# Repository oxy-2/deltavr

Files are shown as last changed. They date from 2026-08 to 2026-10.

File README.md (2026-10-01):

hi im oxy and im working with 2 of my friends (John/monizjoao and grand/merekelene) now to bring everyone a opensource, pcvr, light weight slam tracked headset with constellation tracked controllers and if you are able to source the parts right it could be possible to build your own under 700 euros.

# deltavr

## summary
so to sum up everything in this project, the pcbs are custom for the headset and for the controllers, we are using high performance imus those being the lsm6dsvs, the pcbs are majority smd, the controllers and headset use the widely available and powerfull NRF52840 "pro micro" boards of which are similar to the nice!nano v2, from communication between the headset and controllers gt-24 nrf24l01 boards are used which allows for antennas externally but work great with the MIFA they have, our optics are a big point of this headset too, being that they are pseudo pancakes, basically two fresnels stacked in a way that we can get close to pancake performance but instead of spending hundreds its about 20 euros in total, the entire headset apart from the linear rods is 3d printable and we are doing ours in asa which we will smooth later to get a very nice smooth finish, the headset uses 5 OV9281 120fps global shutter usb cameras which go to a usb 3.2 gen 2 hub which then goes to a pc, speaking of obviously this headset is pcvr, maybe some day it will be mobile but we dont have anything yet in plans for such a thing for the first versions atleast, the last couple points woud be that the controllers are actually nice, sporting a tmr joystick to ensure they do not drift ever while using a low ammount of battery and also 2 hall effect triggers allowing for not just on of off triggers but a range of values.

## reasoning on protocols used:
firstly the usb cameras, they are expensive, alot more so that mipi when they are the usb version, but we do not have any real way of actually converting camera mipi to one central usb as that would alone be an engineering project, secondly the protocol for the mcus to communicate is Nordic Semi's ESB (Enhanced ShockBurst) protocol which we are using for better battery life with great connectivity.

## what we have done right now
as of writing this (october 1st 2026) we have the PCBs fully completed which i did over the previous summer, we have the full bill of materials and general plan too done and a general idea of the 3d design for the controllers while we are actively modeling the headset rn and have it about 30% done id say, the PCBs do need one made for the left version of the controllers but that is a very simple thing to do and i will be doing it soon, along with a full bom we have all the parts fully sourced and ready for purcahse through aliexpress and alibaba for their competetive pricing of electronic components and availability of them, we are sourcing really just the cameras from alibaba and also the imus we are purchasing in bulk from a seller directly who was found on alibaba at first.

## where can you see our work?
well theres my personal site at oxygenated.uk but i still need to update its information and then theres this github repository and the weekly reports for thirdspace my team and i write which include lapse links of which can be used to view all the work we have done in a time lapse format.

thank you for your time.

\-oxy <3

JohnTarkov: Hi im JohnTarkov Im working on the project too and i updated this so i can get my hacktime functioning for the project to use Lookout to record my project.

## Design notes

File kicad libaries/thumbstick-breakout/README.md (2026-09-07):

# "PS5 Hall Effect" Compatible Thumbstick Breakout Board
This breakout board is designed to be a drop-in replacement for the Sparkfun BOB-09110 but using hall effect thumbsticks instead of low quality "PS2 style" sticks.

These thumbstick components are widely available on Ali Express as replacement thumbsticks for game controllers. Unlike a traditional potentiometer based joystick, these sticks only operate with a specific polarity, so ensure you select one meant specifically for the PS5 to match the design of this board.

PCBWay order link:<br/>
https://www.pcbway.com/project/shareproject/_PS5_Hall_Effect_Thumbstick_Breakout_Board_abc13f47.html<br/>
(10 for $5 at time of writing. I get a small commission.)




## Datasheet
I couldn't find a datasheet for these stick components, but the datasheet for [this alternative](https://mm.digikey.com/Volume0/opasdata/d220001/medias/docus/2608/THB001P%20drawing.pdf) stick seemed to have measurement information the exact same footprint, so it was used in the creation of this board.

## License
Copyright (c) Daniel Benoy

Distributed under the terms of the [Creative Commons ShareAlike 4.0 International](https://creativecommons.org/licenses/by-sa/4.0/) license.

THESE FILES ARE PROVIDED BY THE COPYRIGHT HOLDERS AND CONTRIBUTORS “AS IS” AND ANY EXPRESS OR IMPLIED WARRANTIES, INCLUDING, BUT NOT LIMITED TO, THE IMPLIED WARRANTIES OF MERCHANTABILITY AND FITNESS FOR A PARTICULAR PURPOSE ARE DISCLAIMED. IN NO EVENT SHALL THE COPYRIGHT OWNER OR CONTRIBUTORS BE LIABLE FOR ANY DIRECT, INDIRECT, INCIDENTAL, SPECIAL, EXEMPLARY, OR CONSEQUENTIAL DAMAGES (INCLUDING, BUT NOT LIMITED TO, PROCUREMENT OF SUBSTITUTE GOODS OR SERVICES; LOSS OF USE, DATA, OR PROFITS; OR BUSINESS INTERRUPTION) HOWEVER CAUSED AND ON ANY THEORY OF LIABILITY, WHETHER IN CONTRACT, STRICT LIABILITY, OR TORT (INCLUDING NEGLIGENCE OR OTHERWISE) ARISING IN ANY WAY OUT OF THE USE OF THIS SOFTWARE, EVEN IF ADVISED OF THE POSSIBILITY OF SUCH DAMAGE.

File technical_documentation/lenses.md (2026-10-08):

# DeltaVR - dual fresnel optics

> [!summary] summary
> d.70 pmma fresnels, **2 mm** thick each. stack is **f40 (display) + f30 (eye)**, grooves side meeting at the middle seperated by the gasket (*0.2mm*)
> combined efl **≈ 17.2 mm**. display gap is **15.0 mm**. eye relief is **20 mm** design (15–22 band). 10 mm is lashes-on-glass and the nose will not fit.

**parts:** d70 fl30 (top) + d70 fl40(bottom), 5 € ish each also buy spares. 

**cut outline:** see `deltavr-lens-cut.png` (optical center on pupil, nose bite, mirror L/R). trim does **not** change focal length (fl).

---

## 1. layout

```
display active surface
   │
   |  15.0 mm air          <-- dist. to disp. from len not holder, thats 14mm
   ▼
   f40 fresnel  2 mm       flat side toward display, grooves inward
   │
   │  0.2 mm spacer        printed as first layer (ring, not take up fov too much)
   ▼
   f30 fresnel  2 mm       grooves inward, flat toward eye <- top is more focused
   │
   │  20 mm air            eye relief (15–22 band, 25 if glasses)
   ▼
cornea of eye
```

| gap | value | notes |
| --- | --- | --- |
| display -> f40 flat | **15.0 mm**  | caliper this. 14 = near focus, 15 = infinity-ish, 16 = far bias |
| f40 thickness | **2.0 mm** | catalog, cat. shouldnt change |
| between lenses | **0.2 mm** | grooves face each other. ring spacer, not a disc |
| f30 thickness | **2.0 mm** | catalog |
| f30 flat -> eye | **20 mm** | design. 15–22 band. 25 if glasses. 10 = lashes + nose smash |
| **optical module** | **19.2 mm**  | display face → outer face of eye lens. cylinder depth |
| **display -> cornea** | **~39.2 mm** | includes eye-relief air. do **not** put this in the barrel |

---

## 2. sign convention

real-is-positive, thin-lens form:

$$\frac{1}{f} = \frac{1}{d_o} + \frac{1}{d_i}$$

virtual image (eyepiece case) → $d_i < 0$.

---

## 3. single lens

| symbol | meaning | value |
|---|---|---|
| $f$ | focal length (efl) | 30 mm or 40 mm |
| $d_o$ | object distance (display → lens) | solve |
| $d_i$ | image distance (lens → image) | $-\infty$ or $-250\ \mathrm{mm}$ |
| $t$ | substrate thickness | **2.0 mm** |
| $n$ | pmma index | 1.49 (catalog fl already includes this) |

> [!note] fresnel fl reference
> catalog fl is measured from the **grooved surface**. the 2 mm blank is mechanical dead plastic; power lives on the grooves. that is why $g_{\mathrm{disp}} = \mathrm{FFL} - t$.

---

## 4. two thin lenses, separation $d$

groove-to-groove: $d = 0.2\ \mathrm{mm}$.

$f_1 = 40$ (display side), $f_2 = 30$ (eye side).

### equivalent focal length

$$\frac{1}{f_{\mathrm{eq}}} = \frac{1}{f_1} + \frac{1}{f_2} - \frac{d}{f_1 f_2}$$

$$\frac{1}{f_{\mathrm{eq}}} = \frac{1}{40} + \frac{1}{30} - \frac{0.2}{40 \cdot 30} = 0.025 + 0.033333 - 0.000167 = 0.058167$$

$$\boxed{f_{\mathrm{eq}} = 17.19\ \mathrm{mm}}$$

contact limit ($d \approx 0$):

$$f = \frac{f_1 f_2}{f_1 + f_2} = \frac{1200}{70} = 17.14\ \mathrm{mm}$$

---

## 5. front focal length (display placement)

object at front focal point → image at infinity (relaxed eye). ffl is measured from the **first lens groove plane** ($L_1$ = f40).

$$\mathrm{FFL} = f_{\mathrm{eq}}\left(1 - \frac{d}{f_2}\right) = 17.19 \times 0.99333 = 17.08\ \mathrm{mm}$$

principal-plane offset from $L_1$ is $\bar{H_1} = -f_{\mathrm{eq}}\, d / f_2 \approx -0.12\ \mathrm{mm}$. negligible. treat the f40 groove plane as the front reference.

**mechanical gap (flat → display):**

$$\boxed{g_{\mathrm{disp}} = \mathrm{FFL} - t_1 = 17.08 - 2.0 = 15.1\ \mathrm{mm} \approx 15.0\ \mathrm{mm}}$$

---

## 6. focus target (not just infinity)

$$\frac{1}{d_o} = \frac{1}{f_{\mathrm{eq}}} - \frac{1}{d_i}, \qquad d_i = -|d_i|\ \text{(virtual)}$$

$$d_o = \left(\frac{1}{f_{\mathrm{eq}}} + \frac{1}{|d_i|}\right)^{-1}$$

$$\boxed{g_{\mathrm{disp}}(d_i) = \left(\frac{1}{f_{\mathrm{eq}}} + \frac{1}{|d_i|}\right)^{-1} - t_1}$$

| target image | $\|d_i\|$ | $d_o$ (to groove) | $g_{\mathrm{disp}} = d_o - t_1$ |
|---|---|---|---|
| infinity (relaxed) | $\infty$ | 17.1 mm | **15.1 mm** |
| 2 m (far) | 2000 | 16.4 mm | 14.4 mm |
| 25 cm (reading) | 250 | 16.1 mm | **14.1 mm** |
| 10 cm (too close) | 100 | 14.4 mm | 12.4 mm |
| 6 cm (why 13.2 hurts) | 58 | 13.2 mm | 11.2 mm |

> [!warning] old 13.2 mm gap
> manolo's measured 13.2 mm doesnt match 30+40 thin lens math. it puts the virtual image at ~6 cm and eyes will hate it. if a housing is already cut at 13.2, print a ~2 mm shim. design point is **15.0 mm**, shim range **14–16 mm**.

---

## 7. eye side

firstly, eye relief is mechanical not optical:

$$g_{\mathrm{eye}} = \mathrm{cornea} - \mathrm{f30\ flat}$$

| use | $g_{\mathrm{eye}}$ |
| --- | --- |
| lashes / fantasy | 8–10 mm |
| aggressive nose trim | 15–18 mm |
| **design (fits a face)** | **20 mm** |
| glasses / easy fit | 22–25 mm |

10 mm is eyelashes on the flat. the nose also will not fit: nose tip sits ~25–45 mm in front of the cornea, so at 10 mm relief the bridge is still deep inside the lens volume. 20–25 mm is the real mechanical floor for a full ø70 stack and a normal nose. closer than that needs a molded face interface almost nobody will print right on try one.

first-order fov does **not** care about relief. relief buys eye box and clearance.

$$r_{\mathrm{clear}} \gtrsim g_{\mathrm{eye}} \cdot \tan(\mathrm{FOV}/2) + \mathrm{eye\ box}/2 + r_{\mathrm{pupil}}$$

at fov 75°/axis (tan 38° ≈ 0.78) and a 5 mm eye box:

| $g_{\mathrm{eye}}$ | $r_{\mathrm{clear}}$ needed | note |
|---|---|---|
| 10 mm | ~16 mm | easy, but lashes |
| 20 mm | ~23 mm | keep this radius on the **temple + top** |
| 25 mm | ~27 mm | almost untrimmed ø70, nose dies |

so: do **not** shrink the whole lens. cut a **nose bite only** (manolo kidney / d-shape). keep r = 35 mm on the outer, top, and bottom-temporal edges. inboard at pupil height, clear down to ~18 mm from the optical center (≈13 mm from midline at 63 ipd). below pupil height the bite opens more for the nose body.

inboard eye box will be tighter than outboard. that is normal. lose a little binocular overlap before you lose temple fov.

---

## 8. full stack length

### optical module

ends at the outer face of the eye lens, **not** at the cornea.

$$L_{\mathrm{mod}} = g_{\mathrm{disp}} + t_1 + d + t_2$$

$$L_{\mathrm{mod}} = 15.0 + 2.0 + 0.2 + 2.0 = \mathbf{19.2\ \mathrm{mm}}$$

### display → cornea

$$\boxed{L_{\mathrm{total}} = g_{\mathrm{disp}} + t_1 + d + t_2 + g_{\mathrm{eye}} = 15.0 + 2.0 + 0.2 + 2.0 + 20.0 = 39.2\ \mathrm{mm}}$$

| $g_{\mathrm{eye}}$ | $L_{\mathrm{total}}$ display→cornea | housing $W_{\mathrm{FB}}$ (approx) |
|---|---|---|
| 15 mm | 34.2 mm | ~44 mm |
| **20 mm (design)** | **39.2 mm** | **~49 mm** |
| 25 mm | 44.2 mm | ~54 mm |

quest 2 body is ~48 mm. 20 mm relief puts us at quest-class thickness, not "thin". the thin goal dies here unless relief or the optical module shrinks. do not fake it with 10 mm.

### housing front-back (mechanical)

$$W_{\mathrm{FB}} = t_{\mathrm{display\ PCB}} + t_{\mathrm{cover}} + L_{\mathrm{mod}} + g_{\mathrm{eye}} + t_{\mathrm{face\ gasket}}$$

$$\approx 5 + 1 + 19.2 + 20 + 4 \approx \mathbf{49\ \mathrm{mm}} \quad (\sim 45\ \mathrm{mm}\ \text{if pcb+gasket squeezed})$$

> [!danger] dont double count
> do not put eye relief inside the optical cylinder. module is 19.2 mm. the 20 mm of air in front of the eye is outside the barrel.

> [!warning] nose bridge
> no solid bar between the lens bottoms. the nose has to climb into the open gap after the nose bite. route structure over the top and along the temples. face gasket gets a deep nose cutout that matches the lens bite.

---

## 9. fov

panel is the LS029B3SX02, active $w = 26.6\ \mathrm{mm}$, half-width $h = 13.3\ \mathrm{mm}$.

### ideal

$$\mathrm{FOV}_{1\mathrm{D}} = 2 \arctan\left(\frac{h}{f_{\mathrm{eq}}}\right) = 2 \arctan\left(\frac{13.3}{17.19}\right) = \mathbf{75.4°}$$

diagonal (square panel, half-diag $= h\sqrt{2}$):

$$\mathrm{FOV}_{\mathrm{diag}} = 2 \arctan\left(\frac{h\sqrt{2}}{f_{\mathrm{eq}}}\right) = 2 \arctan\left(\frac{18.81}{17.19}\right) = \mathbf{95.2°}$$

general:

$$\boxed{\mathrm{FOV} = 2 \arctan\left(\frac{d_{\mathrm{sensor}}}{2\, f_{\mathrm{eq}}}\right)}$$

### real (relief + diameter losses)

relief does not change the 75°/axis first-order number. it changes whether your pupil can sit in the ray bundle (eye box) and how hard the nose bite clips the inboard field.

$$r_{\mathrm{clear}} \gtrsim g_{\mathrm{eye}} \cdot \tan(\mathrm{FOV}/2) + \mathrm{eye\ box}/2 + r_{\mathrm{pupil}}$$

keep r ≥ 23 mm on temple/top at 20 mm relief. nose bite can go down to ~18 mm from the optical center inboard. expect **5–10° less** on the diagonal after nose bite + a little eye-box loss. still quest 2-class (~75° / ~95° ideal).

---

## 10. alternate stack (two f30s)

only real shrink lever. same blank, same cutout, one part number.

$$f_{\mathrm{eq}} = \frac{30 \cdot 30}{30 + 30} = 15.0\ \mathrm{mm}$$

$$g_{\mathrm{disp}} = 15.0 - 2.0 = 13.0\ \mathrm{mm}$$

$$L_{\mathrm{total}} = 13 + 2 + 0.2 + 2 + 20 = 37.2\ \mathrm{mm}$$

$$\mathrm{FOV}_{1\mathrm{D}} = 2\arctan(13.3/15) = 82.0°$$

| stack | efl | display gap | display→cornea ($g_{\mathrm{eye}}=20$) | fov / axis |
|---|---|---|---|---|
| **f40 + f30** (current) | 17.2 mm | 15.0 mm | 39.2 mm | 75° |
| f30 + f30 | 15.0 mm | 13.0 mm | 37.2 mm | 82° |

f30+f30 buys +7°/axis and 2 mm less path. it does not fix the nose. nose is trim + gasket + open nose bridge.

---

## 11. diameter (keep ø70)

matching diameters with **both** fl30 and fl40 in the listing:

| diameter | fl30 | fl40 | both? |
|---|---|---|---|
| **d70** | yes | **yes** | **only option** |
| d90 | yes | (fl50) | no |
| d100 | | yes | no |
| d60 | yes | (fl80) | no |
| d50 / d40 | no | no | no |

d100 fl120 at 10 € is a trap. cutout work stays valid on ø70.

---

## 12. variable sheet

| variable | symbol | formula | value |
|---|---|---|---|
| display-side fl | $f_1$ | catalog | 40 mm |
| eye-side fl | $f_2$ | catalog | 30 mm |
| lens thickness | $t_1, t_2$ | catalog | 2.0 mm each |
| spacer | $d$ | first layer | 0.2 mm |
| combined efl | $f_{\mathrm{eq}}$ | $\left(\frac{1}{f_1}+\frac{1}{f_2}-\frac{d}{f_1 f_2}\right)^{-1}$ | **17.19 mm** |
| front focal length | ffl | $f_{\mathrm{eq}}(1 - d/f_2)$ | 17.08 mm |
| display gap (mech) | $g_{\mathrm{disp}}$ | $\mathrm{FFL} - t_1$ | **15.0 mm** |
| focus target | $d_i$ | design choice | $\infty$ or $-250\ \mathrm{mm}$ |
| object distance | $d_o$ | $\left(\frac{1}{f_{\mathrm{eq}}}+\frac{1}{\|d_i\|}\right)^{-1}$ | 17.1 / 16.1 mm |
| eye relief | $g_{\mathrm{eye}}$ | mechanical | **20 mm** (15–22) |
| optical module | $L_{\mathrm{mod}}$ | $g_{\mathrm{disp}}+t_1+d+t_2$ | **19.2 mm** |
| display→cornea | $L_{\mathrm{total}}$ | $L_{\mathrm{mod}}+g_{\mathrm{eye}}$ | **39.2 mm** |
| half panel | $h$ | $w/2$ | 13.3 mm |
| fov / axis | $\mathrm{FOV}_{1\mathrm{D}}$ | $2\arctan(h/f_{\mathrm{eq}})$ | **75°** |
| fov diagonal | $\mathrm{FOV}_{\mathrm{diag}}$ | $2\arctan(h\sqrt{2}/f_{\mathrm{eq}})$ | **95°** |
| diameter | $D$ | keep cutout | 70 mm |
| ior | $n$ | pmma | 1.49 |

---

## 13. what is *not* in the math

- **$t = 2\ \mathrm{mm}$ does not change $f$.** fresnel power is the groove prism angles. thickness only enters as $g_{\mathrm{disp}} = \mathrm{FFL} - t$ because catalog fl is from the grooves.
- **cutting the outline does not change $f$.** trim is mechanical only.
- **thick-lens principal-plane shift** $\bar{H} \sim t/n \approx 1.3\ \mathrm{mm}$ matters for bulk lenses. for a fresnel with all power at one face, the principal plane sits at the grooves. already handled.
- **seidel aberrations, distortion, astigmatism.** not first-order. the pair (stronger toward the eye) trims some spherical aberration vs a single element; it does not change the first-order numbers above.

---

## 14. build rules

1. optical center (groove center) stays on the pupil.
2. grooves meet in the middle; flats face display and eye.
3. f30 (shorter fl, "more focused") goes toward the **eye**. f40 toward the **display**.
4. spacer is a ø70 **ring** (od 70, id = clear aperture). nothing plastic over the optical zone.
5. no soldering iron on faces. acrylic cement on the outer rim only, or a mechanical ring cassette. heat warps grooves and the lens is dead.
6. mirror the cut outline for left/right. hand-trim is the known-good path.
7. shim the display gap. 15.0 mm nominal, 14–16 mm is the useful window.
8. **nose bite only**, do not shrink the whole blank. keep r = 35 mm outer/top. inboard at pupil height cut to ~18 mm from optical center. below pupil the bite opens for the nose body. see `deltavr-lens-cut.png`.
9. face gasket gets a deep nose cutout matching the bite. no solid nose bridge bar between the lens bottoms.
10. eye relief 20 mm nominal. 15 mm if the trim is aggressive and the face is narrow. 25 mm for glasses. never 10 mm.

---

## 15. summary

$$f_{\mathrm{eq}} = 17.2\ \mathrm{mm} \implies g_{\mathrm{disp}} = f_{\mathrm{eq}} - 2 = 15.0\ \mathrm{mm}$$

$$L_{\mathrm{total}} = 15+2+0.2+2+20 = 39.2\ \mathrm{mm}, \quad \mathrm{FOV} \approx 75°/95°$$

eye relief 20 mm (15–22). 10 mm is lashes and no nose. fov is set by display / efl, not by relief. relief buys nose clearance and eye box. cut a nose bite, keep the rest of the ø70.

---

*deltavr optics · 2 mm pmma · ø70 · f40+f30 · spacer 0.2 mm*

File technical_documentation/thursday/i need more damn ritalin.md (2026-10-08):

okay so to get started we have some objectives, right now we are putting the modelling work on hold until this weekend when we work in unison and show grand and explain how to model in onshape, we have renode to lean too, joao and me we need to get it working on our computers so we can work with grand in unison properly on not just the modelling as the headset is getting more and more polished.

to do list:

- [ ] we need to transfer all products to be purchased over to alibaba and make a propper list of all the tools we will be buying

- [ ] apply for funding with hackclub blueprint and the other hackclub funding thing

- [x] figure out the logistics of hand shipping through europe, mainly latvia to poland

- [ ] build a custom pcb for the smol slimes to be sold to reimburse the price of the headset

- [ ] purchase the screens and lenses

- [ ] fix the 3d printer

- [ ] model the controllers

- [ ] build the first physical prototype of the current hmd model to physically modify it to figure out what to model

- [ ] get and setup the "open" chromebooks that are to be given by Prof. M. 

- [ ] get a good night of sleep

- [ ] read the bible verse that was supposed to be read

- [ ] talk with grand on how shipping and purchasing will be done

- [ ] set a concrete date to buy the imus and also start negotiating the shipping price on other items to be sent to Latvia for lower prices

- [ ] figure out swiss to madeira / slovakia to madeira "buisness trip" if it is selected to be done

- [ ] get confirmation to skip school for days for flight

- [ ] write the portugese translation of your work from pt class

- [ ] test and recalibrate the printer to work with a 0.4 / 0.3 brass nozzle with asa for precision

- [ ] ensure the printer is setup to do overnight prints propperly

- [ ] make sure the enclosure works

- [ ] get money for next week lunches

- [ ] get 11 eur and pay it back over time to get out of debt

- [ ] take a break tmrw and wake up late

- [ ] propperly maintain documentation

- [ ] setup obsidian and git on the school chromebook for writing documentation in free time

- [ ] talk with joao

- [ ] start work on the modeling of the controllers

- [ ] practice soldering and desoldering smd caps and resistors and small qfn parts

- [ ] find out about buying more filament

- [ ] figure out abt getting my ship accepted on stardance

- [ ] buy pcbs with stardance

- [ ] figure out how to get mimo to be accessible thru my phone

i think for now thats about it.

okay so my issue is that i need to propperly organize this all and have everything worked through piece by piece and the rest of my time i spend writing and planning this all out and i need to figure out how to have a connection to my agent at home or my harness and its memory, ill figure it out, yeah lemme add that.

okay i will get started with alibaba transfer of all the items we are gonna buy

and i need to remember every screenshot with my info in it or sum is a screenshot and minute i have to entirely cut from what ive done, use your phone if you need something, never the pc.

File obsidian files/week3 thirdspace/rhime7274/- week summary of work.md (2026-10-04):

so this week was amazing, me and João did a bunch of work together and the model is really getting to its closer to actually being done and its really exciting to see.

so firstly our first design of the lenses was utter dogshit icl heres a peep from the images in the last devlog lol.

![[old lenses.png]]

anyways so you can see first of all the lenses were uncut and well this one actually didnt have lenses lol but yeah so like it had the lenses separated as far as possible vertically where as it turns out you actually dont want that, you can refer to my documentation on how it actually works if you want its well ill just link it buts a obsidian link yk, anyways [here](obsidian://open?vault=GitHub&file=deltavr%2Ftechnical_documentation%2Flenses%20assembly%20and%20lenses%20formulas%2Flenses)

so you can see with the calculations and such to back it up there, but in short you want the lenses as close together as possible and as long as you can get them close which we had to space em but yeah, but yeah if you can get em close you can have em close to the screen, very close and then have your face like only 10mm away for eye relief so like it cuts down the size a lot which is a massive bonus considering how cheap it is of an upgrade only needing one extra lens pair, anyways so we like ended modeling out the like double lens guy heres a photo.

![[new lenses.png]]

so as you can see the two lenses stacked there on the left thats without the like assembly to hold em in place, the gasket between the two lenses to not damage either, and also some holes for mounting and well yeah mounting is a big point of the assembly, i want them to just slot into the like screen area so its like easy to swap em out if you need, tho tbf if you wanna take this thing apart its gonna be like a puzzle lmao anyways you can also see an area in the top dug out, thats for the display connectors which are mirrors of eachother to go to one guy that turns em into just one mipi connection which goes back to our driver board, heres a pick of the small combination board and the bigger driver board.

![[mipi to hdmi board.png]]

straight off aliexpress im sure you can tell, anyways these actually just come right with the screens we are getting which is great and should run at 90hz which will not make the judges hurl which is good but the displays can hit 120hz its a driver limitation but if we spent uhh i say 40 euros more which is a big stretch icl we can use 120hz displays, heres a looksie at the driver board for those.

![[the better mipi to hdmi board.png]]

here you can see it, also i think it offers seperate like mipi ribbons for each rather than one split, which is kinda awesome and i fw the black but its just too expensive to really be viable cuz its a 40 euro bump best case and a 60 or even 80 worst case which just absolutely vaporizes any sense of ever having this thing at like 700 euros, anyways so i also spent a long while thinking of how we will do the headstrap and you can see our discord pins are getting full so i think we will either move to a server or slack maybe idk, like heres a pic of the pins lmao.

![[discord pins.png]]

but yeah i think slack would be the best option especially since its very easy to go see the hackclub channels too then anyways so other than this i also finally got the pcb mounting down, its inset into the actual like front of the hmd and its gonna use very thin flat topped m3 screws with nuts on the outside facing air, so it meets like constraints of like not wanint the displays to be fucked with or sliders at all, heres a image.

![[front pcb inset.png]]

the last real thing i can think of that i did was the great organization and naming and starting with the documentation which ill alone be doing where i will write up all the aformulas in detail, all the design specs, everything, anyways heres a pic of the new organization and then ima ship and head off to bed, so sleep well anyone else who might be reading this later than they should be.

![[parts list organization.png]]
![[feature list organization.png]]

by oxy, with love <3

also heres all the lapse links:
https://lapse.hackclub.com/timelapse/YUHhA-L_d-OA
https://lapse.hackclub.com/timelapse/loU83V0GBWJ2
https://lapse.hackclub.com/timelapse/_5qo_6D7EQ2-
https://lapse.hackclub.com/timelapse/pCRKZhMesPzA
https://lapse.hackclub.com/timelapse/ALP4UK4dRvD0
https://lapse.hackclub.com/timelapse/1PGKenvypzti

(they are in chronological order btw)

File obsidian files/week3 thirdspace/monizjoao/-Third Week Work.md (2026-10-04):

So to start off the week me and oxy researched about the lenses and attempted to create a simulation for the ray tracing of the displays through the lenses. This turned out to be a failure and very unnecessary for the modeling of the lenses themselves. Oxy directed me on how to go about modeling the lenses and I started with a simple circle to find the optical center of the displays.

![[Pasted image 20261004204713.png]]
*Optical center of displays*

*Lapse for the circle lenses before cut:* https://lapse.hackclub.com/timelapse/2Iiws-dVEZlJ

After creating the circle displays I started making the holders for them. They needed to be made in three parts and also needed a gaskets and two bumpers to squish the lenses. The gasket stays in the middle to separate the two fresnel lenses.

Then Oxy helped me cut the lens model to into the shape we wanted the lenses to have. I used the spline tool and a bunch of focal points to model it out. They turned great and the only problem is that we couldn't make sketches on the sides but that was fine since we never ended using that part so whatever.

After this I started on the cut lens holders. Using the Use tool i selected the outline of the lenses and offset it by 2mm in thickness. Then I extruded it into 2 separate parts unlike the circle ones that took 3 parts. These parts were initially 2mm in depth each but we had to thicken them up a bit so they ended up being 3mm each. Then Oxy made the shell on the lens holders and then we made holes on them for pins. These are for prototypes only however since the final project is planned that we'll just glue the 3 parts together and the pins are just to hold them temporarily. 

![[image.png]]
*Distance from optical center*

![[Pasted image 20261004205421.png]]
*Sketch for the actual lenses*

*Lapse for the circle lens holders, the cut lens modeling and the cut lens holder modeling:* https://lapse.hackclub.com/timelapse/bXOdZ73r5PyK

Then it was just a matter of moving the lenses 14-15 mm in front of the displays for the fresnel lenses to give clear imaging. To do that I used the circular lens sketch to move the central point of the cut lenses into the central point of the circular ones. Then a bit of adjusting just to make the lenses fit snuggly in front of the display without any part of the lens going over the display.

I also took a bit of time during the moving of the lenses to research about how fresnel lenses work and how it was gonna work on the headset.

![[Pasted image 20261004215321.png]]
*Google patent on the fresnel based verifocal lens assembly for VR or AR displays*

*Lapse for the research and moving of the lenses:* 
https://lapse.hackclub.com/timelapse/2pfvhc1sCmSp

After this I started working on the halo strap for the headset (although my version was scrapped afterwards by myself). This halo strap consisted of 2 parts that were bound together by 2 pins. Then the actual strap was just a solid circle of plastic with no measurements other than circumference of the human head.

![[Pasted image 20261004215835.png]]
*Pins after the halo was scrapped*

![[Pasted image 20261004215920.png]]
*Pins before the halo was scrapped*

I also took a while to figure out how to make a solid ramp for the forehead to fit more comfortably (which probably is wrong too but we're working on it).

![[Pasted image 20261004220047.png]]
*Ramp for forehead ergonomics*

*Lapse for the modeling of the halo strap:* https://lapse.hackclub.com/timelapse/MqMv9uNgF1EC

To end the week off i made a little part for the displays to hold the lens holders which ended up being scrapped aswell.
![[Pasted image 20261004220329.png]]
*Bridge for the holders to the displays*

*Quick lapse for this part:* https://lapse.hackclub.com/timelapse/SGPlCAp-nYkq

I also wrote this very entry on the journal.

---
Final thoughts:
This week was stressful. Especially since I finished my hours so late. I didn't do any work on monday which wasn't really a good idea but I was really tired and I was having a really rough week altogether due to outside factors.

Aspirations for next week:
I hope next week I can actually clear my head and lock in to do my hours quickly so I can hop on Tarkov by the end and relax.

*Lapse for writing this entry:* https://lapse.hackclub.com/timelapse/24A70LW7OrKx

Links for the lapses:
https://lapse.hackclub.com/timelapse/2Iiws-dVEZlJ
https://lapse.hackclub.com/timelapse/bXOdZ73r5PyK
https://lapse.hackclub.com/timelapse/2pfvhc1sCmSp
https://lapse.hackclub.com/timelapse/MqMv9uNgF1EC
https://lapse.hackclub.com/timelapse/MqMv9uNgF1EC
https://lapse.hackclub.com/timelapse/24A70LW7OrKx

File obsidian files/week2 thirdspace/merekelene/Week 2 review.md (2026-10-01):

---
Naming gpio's :
A grand whoping 1 hour of this week was spent finishing a task that i started last week, that is the naming and sorting of all gpio connections between the pro micro nrf board we are using and all the peripherals.

![[Gpio naming showcase.png]]

My group member liked this comprehensive assortment of connections and links between peripherals so much that he asked that i add it to our github repository, so now it is apart of the project files instead of being a little list of notes that only i use for making the firmware in the future.

https://lapse.hackclub.com/timelapse/yI_2YMaBX_g9
https://lapse.hackclub.com/timelapse/dq2dJCWjqWjy
---
Looking for components :
After last weeks failure to get a logical handle on the workings of renode the hellish emulation software, i decided to look for only the necessary components to make a real life testing device, it would have two controllers with all their peripherals and id be able to use arduino ide most likely to program them by writing c in a comprehensible environment and quite quickly get the firmware working, with a little bit of debuging, but it would at least be better than renod because it would actually let me test. Is it reasnable to say i curently dont like renode? anyway.

I looked for components on ali express and found a some good options but when i finally thought i could check out the price had doubled because of eu import tax, so i started thinking and remembered about alibaba, witch in my experience is usually cheaper by a significant margin.

![[cheeper components than on aliexpress.png]]

Later i spoke to my team and double checked what items i had found and i was informed that we have switched out a radio module from the old one witch had a range of 1km to a much more reasonable module 1.1km, because that is not excessive at all for a vr headset and its controllers witch will not ever be more than 2 meters away.

![[new radio module.png]]

After talking about the prices and noticing that shipping for me from china costs close to zero while for my teammates it costs an arm and a leg, we had the idea that maybe i can order the components from china and send them to them as that would still be cheaper. while we were talking about that i was tasked with checking the price for a type of camera and its lenses as the headset will utilize cameras as well. for my teammates the camera and lenses combo costs close to 300 euro while for me it was only 100 euro so it is very likely that i will be a sort of logistician for our team. 

![[camera and lenses.png]]

https://lapse.hackclub.com/timelapse/tYNXB_Xn2c5I
https://lapse.hackclub.com/timelapse/TuPlermgICmS
https://lapse.hackclub.com/timelapse/mzj91E8dXs07
https://lapse.hackclub.com/timelapse/WBEe1AnuQdcK
---
Learning to emulate with Renode : 
Same as last week i am fighting with this software and trying to figure out how it works. I used ai a fair bit to try and setup the environment in witch i will work in, as the documentation or any information found about renode is not understandable unless you already know how it all works. 

I dont know if this software really is as complex as it seems as i have gotten it to work, but understanding the filesystem if i can call it that is another thing.

![[file system showcase.png]]

I do believe that i have made a certain breakthrough as i figured out the three primary file types that you need to have to describe and run a simulation.

The first being a ".repl" file that contains the system description like what cpu is being used, memory size and type, peripherals and also communication protocols.

![[small chunk of repl file.png]]

The second being a ".elf" file that is simply the compiled c code that i write as firmware.

![[uncompiled c code that will become an elf file.png]]

The third and last being a ".resc" file that contains launch commands, creates the virtual machine, loads the .repl and .elf, opens windows for logging outputs and lastly starts simulation.

![[resc file.png]]

https://lapse.hackclub.com/timelapse/IxfJfZzC3tDP
https://lapse.hackclub.com/timelapse/awH_BEz8IXAa
https://lapse.hackclub.com/timelapse/fhpDfgZU8DIh
https://lapse.hackclub.com/timelapse/aShfHadrIlBc
---
All lapses in one place (11 lapses) :
Naming gpio's :
https://lapse.hackclub.com/timelapse/yI_2YMaBX_g9
https://lapse.hackclub.com/timelapse/dq2dJCWjqWjy
Looking for components :
https://lapse.hackclub.com/timelapse/tYNXB_Xn2c5I
https://lapse.hackclub.com/timelapse/TuPlermgICmS
https://lapse.hackclub.com/timelapse/mzj91E8dXs07
https://lapse.hackclub.com/timelapse/WBEe1AnuQdcK
Learning to emulate with Renode :
https://lapse.hackclub.com/timelapse/IxfJfZzC3tDP
https://lapse.hackclub.com/timelapse/awH_BEz8IXAa
https://lapse.hackclub.com/timelapse/fhpDfgZU8DIh
https://lapse.hackclub.com/timelapse/aShfHadrIlBc
Making the devlog :
https://lapse.hackclub.com/timelapse/nyf27BeVddA7
---
The end :)

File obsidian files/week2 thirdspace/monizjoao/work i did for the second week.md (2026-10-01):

This second week me and Oxy focused on modeling the IPD stuff for the headset and also how the displays and lenses are gonna be.
Firstly we did a rack and pinion system as a prototype although this was changed later.
![[Pasted image 20260927151430.png]]
(Early prototype of the rack and pinion system.)
![[Pasted image 20260927151546.png]]
(Assembly simulation of the rack and pinion system.)
Lapse for the rack and pinion system: https://lapse.hackclub.com/timelapse/Yn8y69aQsNER

This system was ok for what we were gonna do but it was hard to model and actually implement so we decided to change it to a sliding assembly with metal rods and a display plate.
This system wont doesn't do anything as of right now but eventually we'll make it work.
[Pasted image 20260927151949.png]
Lapse for the remade system: https://lapse.hackclub.com/timelapse/JYO1MD31HEyD

Modeling the rod system consisted of figuring out the measurement of the rod itself and sticking it into the headset on the right spot before modeling the end caps.
Then we figured we'd use small holders to hold the displays.
[Pasted image 20260927152620.png]
Lapse for the early holders: https://lapse.hackclub.com/timelapse/zojeA41YhIfv

To hold the displays I modeled the holders to have a flush fit to the displays as kind of like slots but that didn't work so Oxy asked me to model a dovetail for the holders which we also ended up not using.
![[Pasted image 20260927153111.png]]
(Unused dovetail model)

At the end we decided to actually use some sort of adhesive for the displays so we made a much simpler slot system that consisted of four long cylinders with a plate between them and clearance of 0.6mm between them and the rod so they can slide around. 
![[Pasted image 20260927153350.png]]
(New display holder system)

After finishing this we decided to finally address the elephant in the room and fix all the errors the 3d model had. Approximately one third of the parts we had on the project were not generating because of errors. 

Firstly we made a new branch for the project in case we messed anything up. After that we got to work and deleted a bunch of parts that had generation errors.
We also used that time to delete a bunch of transforms we had that were essentially clogging the program up with bloat that was unnecessary.
![[Pasted image 20260927153837.png]]
(Before the debugging)
![[Pasted image 20260927153908.png]]
(After the debugging)
Lapse for the holder system the dovetail and debugging: https://lapse.hackclub.com/timelapse/DXPoKPyp0mUW

During this whole IPD system remake we had the headset hidden to be able to work on the mechanics without having the headset blocking our view. Unfortunately when we reopened the file it so happened that the holders clipped through the headset which was a problem. For this reason we took another hour to make bumps on the outside of the headset in order for the holders to fit.
![[Pasted image 20260927154602.png]]
(Bumps on the outside of the headset)
Lapse for this part: https://lapse.hackclub.com/timelapse/vdHVwVGbpihZ

After the bumps were completed I worked on the lens holders which genuinely will absolutely not work its just a placeholder for now as its not attached to any mechanical parts that would move it for the IPD adjustment.
![[Pasted image 20260927155630.png]]
(Highlighted part is the place holder)
Lapse for the place holders: https://lapse.hackclub.com/timelapse/KMbGio_Hn6Kq

To finish this week off like the last one I did the obsidian journal for shipping the project.

Notes: This week me and Oxy went to our school's administration to ask them for four applications for our school Chromebook so we can work on the project at school. These applications were: Brave, Obsidian, ACode and Termux but by APK install. Oxy needed to write a whole letter for the company that manages the school Chromebooks. You can see the redacted versions on Oxy's folder for this week's journal. It is redacted as to not dox our identities further than what we exposed already.

Final thoughts: This week I worked pretty well and I actually had a lot of time in my weekend for leisure as I worked for a good time throughout the week. The fact that we managed to get work done in the Chromebook sped the progress up and I have a feeling next week we'll be even faster.

Lapse for writing this entry: https://lapse.hackclub.com/timelapse/ZPE9YOWOJFWq

___
Lapse links:
https://lapse.hackclub.com/timelapse/Yn8y69aQsNER
https://lapse.hackclub.com/timelapse/sJLcdh9fHZbd
https://lapse.hackclub.com/timelapse/JYO1MD31HEyD
https://lapse.hackclub.com/timelapse/zojeA41YhIfv
https://lapse.hackclub.com/timelapse/DXPoKPyp0mUW
https://lapse.hackclub.com/timelapse/vdHVwVGbpihZ
https://lapse.hackclub.com/timelapse/KMbGio_Hn6Kq
https://lapse.hackclub.com/timelapse/ZPE9YOWOJFWq

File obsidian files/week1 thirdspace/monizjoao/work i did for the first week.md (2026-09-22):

I started off the week by talking to Oxy about what we're supposed to do and then did some modeling on OnShape (basically figuring out how to make basic shapes and such). After this I ended with a shape kinda like the one highlighted in the following photo.
![[Pasted image 20260920192032.png]]
We had a basic plan on what to do but nothing too advanced at the time. We talked about how we were going to make the modeling for the lenses and what not all while figuring out how to work on OnShape (we ended up not being able to do the lenses yet).
Relapse link: https://lapse.hackclub.com/timelapse/ryS_euUJOcCl

After this we ended up trying to figure out how to import stuff into our project and Oxy figured out how to port the PCB design he made as for the following image.
![[Pasted image 20260920192436.png]]
We also decided to customize the headset a little bit, putting the custom made logo on the front of it.
![[Pasted image 20260920192535.png|700]]
This turned out to be a bad idea because for Oxy it ended up lagging his computer to a point that he couldn't work very well so we had to temporarily remove the logo from the headset. Maybe it was the amount of polygons on the letters that was the spawn of all that lag, who knows.
Relapse: https://lapse.hackclub.com/timelapse/kR3vOfqCb4tG

After that little side quest we started researching and testing together on how to punch holes into the 3D model for the PCB screws. This turned out to be very easy but took quite a bit to figure out and after we learnt I made some standoffs for the PCB to stand on and screw into it.
All this research was made on Claude as it was the fastest way to get tutorials on how to model what we had to model. 
![[Pasted image 20260920201033.png]]
(Chat with Claude)
![[Pasted image 20260920201254.png]]
(HTML Visualization Claude made which was later replaced by putting the PCB on the outside of the headset)
![[Pasted image 20260920193357.png]]
(Holes on the inside of the headset)
![[Pasted image 20260920193406.png]]
(Holes on the front of the headset)
![[Screenshot 2026-09-20 193455.png]]
(Pegs after the extension of their thickness)

Relapse link: https://lapse.hackclub.com/timelapse/xzZs8LcHw93p 

I did have to remake the holes to be smooth because I made them threaded for M3 screws which wasn't necessary since Oxy had heat set inserts.
So after smoothing out the holes and also modifying the pegs to make them thicker as requested by oxy I started to do some research on how to model out a head gasket for the headset on Claude and ChatGPT.
![[Pasted image 20260920193931.png]]
This pretty much lead to not much other than modeling out a bit of an outer edge for the headset to fit on a face easier which I we'll probably end up fitting foam or something soft around it so its more comfortable to wear. 
![[Pasted image 20260920194616.png]]
(Part that was modeled is highlighted)
![[Pasted image 20260920201357.png]]
(Visualization made by Claude)

When I modeled this outer edge was also the time Oxy figured out how to make gears on OnShape which was going to be very helpful for the gear racks used on the IPD adjustment.

At the end of this first week I started work on some more modeling for the insides of the headset. I did some research on how gear racks work and how installed a new plugin to be able to make custom gear racks for the build. I also managed to make a rough gear rack for the 3D model that looks like this:
![[Pasted image 20260920225614.png]]
![[Pasted image 20260920225639.png]]

This is just a prototype for now but when it works the headset will have IPD adjustment.
I should mention that some of the research on how to make a rack was done on a youtube video by [Imants Smidchens] I'll leave the link here on the video and plugin.

Video: https://www.youtube.com/watch?v=Zc7u_Qt6k2g
Plugin: https://cad.onshape.com/documents/a053210cff9307706509be8c/w/038b6b227ae631c4540247a3/e/d16fd899b7879b53cff52db5

After doing the rack itself i worked on making an axel and I'm pretty proud of how I did for the first time.
![[Pasted image 20260920233952.png]]
Basically the dark blue gear will spin the cyan gear which will the move the racks back and forward. These racks will move the lenses and the displays back and forwards simultaneously to adjust to any person's eyes.

After finishing the axel I did some work on pins for the racks so they can actually move left and right. These are just a concept and will be measured and modified later in the project.
![[Pasted image 20260921000253.png]]

As a little extra I modified the front of the headset where the PCB is so the protection covers a millimeter into the PCB just in case the headset falls face first.
![[Pasted image 20260921001426.png]]
(What I modified is highlighted)

To finish it all off I wrote this entry on the dev log to ship all of it to third space.

This pretty much sums up everything I did this week. It wasn't much but I am still learning how this whole CAD thing works. I believe I could've worked a little bit more if it wasn't for the fact that I got distracted with other unproductive things and also school was a big factor in not doing much work. All this considered I believe it was a pretty good first week and I'm learning quite quickly on how to do 3D modeling on CADs.

Relapse: https://lapse.hackclub.com/timelapse/mwjt-r2-Sup0

---
All relapse links:
https://lapse.hackclub.com/timelapse/ryS_euUJOcCl
https://lapse.hackclub.com/timelapse/kR3vOfqCb4tG
https://lapse.hackclub.com/timelapse/xzZs8LcHw93p
https://lapse.hackclub.com/timelapse/B8ednIeUE1pn
https://lapse.hackclub.com/timelapse/mwjt-r2-Sup0

---

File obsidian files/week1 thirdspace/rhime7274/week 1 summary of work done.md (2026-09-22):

so this is the first time I've made a hardware journal lol, anyways so like today we all did a bunch of work to give a rundown of what i had done from start to end of this week

* Manage and properly prepare my team for third.space, and talk with john abt the overall design of the headset which i have rough sketches of in my note book which ill insert, so tldr for this bullet point is managing the team and figuring out the design.

* Secondly i did minor redesigns to the pcb for the hmd to be easier to model, basically i moved the screw holes a little.

* next which is probably the biggest one, onshape modeling, myself and john are starting to model and design the hmd so we have actually well taken the time to learn what onshape is and the basics and then we well got to it, the onshape is actually public view as in anyone with the link can view it without an account, ill drop it later.

* i also spent some time doing things related to my 3d printer, some of which were mistakes as i handled customs on recording which leaked some things and meant i had to delete a two hour timelapse, other than that i tried fixing my old mobo and ended up buying a new skr pico for the printer.

* lastly the items we will use, i had to add some linear rods, move items from alibaba to aliexpress on the case of exorbitant shipping prices reaching around 521 usd for under 200 usd worth of products which was not very uh, good for us being able to buy anything, anyways so i moved almost everything to aliexpress with maybe 3 exceptions, one being something we are purchasing direct from seller.

now i believe that's everything so to go further in depth on all the things ill get some pictures and put them in here, namely pictures of the onshape model, onshape link, the designs from my notebook and other such references and such used for everything one this week, so firstly heres what we modeled out in onshape: 

![[headset model.png]]

and also heres the link to the onshape document to view it, please ignore the random floating gear we are trying to figure out how to make a ipd system lmao.
https://cad.onshape.com/documents/55a6003c2d91dd6c07e81368/w/5233e9f90b08369f7f72aa4e/e/ef4ddb70581f0ac3da42bb7a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

so next would be the note book hand written stuff which are these following images, ill label under them what they all are, note tho these are all the pages related to this project not necessarily just this week tho most of the ones ill put at the top and don't state they were not used this week will have been used as a reference this week fore modeling or architecture, speaking of i need to make a blueprint, great thing for next week, anyways so here are the images:

![[front page book.jpg]]
this is the most recent one ive made of which is  about the controller and hmd design which has further recently been progressed with the use of Microsoft paint however i and john did used this as a reference for the 3d modeling and how to design.

![[second page book.jpg]]
next is this which details how things would be wired and is at least mostly accurate to the now fully complete pcbs, on the second page in this image you can read about the design i suppose, this was not really used this week and i feel the other images of the notebook do not have information of which pertains well to the work this week and hence will be excluding them.

so next would be the pcb and its final state as of this week, so i moved arround some stuff on the hmd and controller pcb i belive, here are pictures of both as of now:

![[controller pcb.png]]
this is the controller pcb, the screw mounting locations changed along with better led placement.

![[hmd pcb.jpg]]
and this is the hmd pcb which i for some reason took a picture of with my phone lol.

of course to end this document here are all the links for the work ive done this week, though one of the 2 hour videos i got had some weird cloudflare error thing on lookout and went from what would have been a perfectly normal recording into just blank tho it atleast still logged, the hours, ill put it here still ofc but ill put a note by it, i hope you understand, also any other missing hours in the relm of 2 to four hours would have been me fighting the customs office here to get my packages to finish fixing my 3d printer as stardance was actually how i got my rpi zero 2 w and i kinda need that to make my 3d printer well work.

https://lapse.hackclub.com/timelapse/uwAyA1MnDNut (the broken one (looks fine now tho?))
https://lapse.hackclub.com/timelapse/E16kel1OWyYN (a time lapse i made to make up for broken)
https://lapse.hackclub.com/timelapse/Xc3pe6G9qaqB
https://lapse.hackclub.com/timelapse/02JU9MNJmJuP (trying to fix 3d printer for this project)
https://lapse.hackclub.com/timelapse/2XFAm0AdBjm3
https://lapse.hackclub.com/timelapse/dFehxUAkY6Uv (the one i wrote this in)
https://lapse.hackclub.com/timelapse/s5blgIAXa4fz (some extra modeling work i did today) 
https://lapse.hackclub.com/timelapse/OxHrwwc8bzsu (set up obsidian for team in this + prev log)

then for the old project with stardance i was keeping up my streak so i also have these lol, also i might in post record more work and add that to the list above.
https://lapse.hackclub.com/timelapse/2STwMfL_oJ3F
https://lapse.hackclub.com/timelapse/ApxFnkfGEOC-
https://lapse.hackclub.com/timelapse/WUaKeM7GO_zN

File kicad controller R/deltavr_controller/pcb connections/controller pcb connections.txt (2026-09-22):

Pro Micro nRF52840 -> lsm6dsvrt : https://lv.mouser.com/en/ProductDetail/STMicroelectronics/LSM6DSVTR?qs=vvQtp7zwQdOfmLUdGphmwA%3D%3D

19 / ain5 p0.29 -> 1 / sdo/sao
31 / p1.01 -> 4 / int1
32 / p1.02 -> 9 / int2
18 / ain0 p0.02 -> 12 / cs
17 / p1.15 -> 13 / scl
16 / p1.13 -> 14 / sda

gnd -> 2 sdx / 3 scx / 6 gnd / 7 gnd
vcc -> 7 vdd_01 / 8 vdd

x -> 10 ocs_aux / 11 sdo_aux

Pro Micro nRF52840 ->  NRF24L01 : https://hackaday.io/page/399497-nrf24l01-module-pinout-features-applications-and-circuit

33 / p1.07 -> 3 / ce
15 / p1.11 -> 4 / csn
17 / p1.15 -> 5 / sck
16 / p1.13 -> 6 / mosi
19 / ain5 p0.29 -> 7 / miso
12 / p1.06 -> 8 / irq

gnd -> 1 gnd
vcc -> 2 vcc

Pro Micro nRF52840 -> ADS1115 : https://www.adafruit.com/product/1085?srsltid=AU7gw4UP4HcsBKbFT9nx8AdIyejDYdWbEtx2y_fzI-sYq8ZmoRRTJUJS

5 / p0.17 -> 9 / sda
6 / p0.02 -> 10 / scl

gnd -> 3 gnd / 1 addr
vcc -> 8 vdd

x - 2 alert rdy

other -> 4/5/6/7

Pro Micro nRF52840 -> ss49e : https://prod-edam.honeywell.com/content/dam/honeywell-edam/sps/siot/en-us/products/sensors/magnetic-sensors/linear-and-angle-sensor-ics/common/documents/sps-siot-ss3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

vcc -> 1 3.3v
gnd -> 2 gnd

ADS1115 -> ss49e : https://prod-edam.honeywell.com/content/dam/honeywell-edam/sps/siot/en-us/products/sensors/magnetic-sensors/linear-and-angle-sensor-ics/common/documents/sps-siot-ss3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

5 / ain1 -> u4 / 3 out1
4 / ain0 -> u3 / 3 out2

Pro Micro nRF52840 -> joystick :

7 / p0.22 -> sel-

vcc -> v+ / h+ / sel+
gnd -> v- / h-

ADS1115 -> joystick : 

6 / ain2 -> h
7 / ain3 -> v

Pro Micro nRF52840 -> buttons :

8 / p0.24 -> sw3
9 / p1.00 -> sw2
10 / p0.11 -> sw1

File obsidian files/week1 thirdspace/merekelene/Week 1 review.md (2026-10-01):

---
Setting up laptop :
I started this week by setting up my laptop which I had not yet been able to do up till now. This was so that I could work both at home and also on the move. This is probably one of the most important things I did as otherwise I most likely would not have had enough time to reach this weeks quota. 

The setup consisted of me installing apps that I will most definitely be using like vscode, renode, github desktop, lookout, hakatime.

![[laptop setup downloading.png]]

I will continue setup next week to include additional libraries needed for Renode.

https://lapse.hackclub.com/timelapse/IjtBbvyHWhr8
---
Learning Renode :
In the last week of the setup phase, I spent some time looking around for a emulator software to test my firmware on, as I am not in possession of the physical hardware that I will be programing. I found two very good options but of the two I ended up choosing Renode because of its wider support for peripherals and many likely uses outside of just this one event. 

![[emulation software.png]]

After finding Renode, I quickly and suddenly came to the realization that Renode is made up entirely by terminals and is not at all similar to what I had in mind, that being Tinkercad or Wowki.

![[emulation software showcase.png]]
(Example of how Renode looks)
After going through the 5 different stages of grief, I finally started trying to figure out how to do all the different things that are necessary to simulate a project. This took a very long amount of time as finding easy to understand and beginner friendly tutorials was difficult. 

with the help of Claude opus 5 I made a basic test project witch included a compiling script, run script and the general hierarchy of files that are necessary for building the virtual controller and also uploading the firmware to it.

![[emulation software test run.png]]
(Test program runing)
https://lapse.hackclub.com/timelapse/3nuWk_uo0MtO
https://lapse.hackclub.com/timelapse/apcl5atXomEH
https://lapse.hackclub.com/timelapse/UcAXlp--94xe
---
Understanding the PCB :
Rhime7274 who invited me to join him in this event had already been doing a lot of work before I joined the team so a significant amount of time was spent looking around the github page looking through schematics, lists of components and other sometimes unrelated files.

The main problem I ran into was that the only schematic showing all the gpio port connections to peripherals was very messy and hard to read so I spent two lapses working on putting them in a more readable format.

From this :
![[pcb.png]]

To this :
![[readable gpio pin conections.png]]

For me this seems like a easier to read format as I can find the connections between components and their pins in a quick glance. I predict this will come in handy when writing the firmware. I will need to update it a bit more but until I have spoken to Rhime7274 about the workings of each segment in depth, it will have to do.

https://lapse.hackclub.com/timelapse/7rRauqIhLzpM
https://lapse.hackclub.com/timelapse/YyGTl8KKhVPs
---
Github and Renode :
Rhime7274 came up with the idea to put my Renode app in the github repo so that all of us would be able to test the firmware virtually. This is my first time using gihub in this way, ever, so at the start trying to communicating where anything on my computer is located and why was frustrating even for me. We spent about half an hour finagling with my files trying all sorts of things but inevitably gave up.

This was all caused by my ignorance and lack of thinking of the future. I had put the Renode app files in a higher directory because otherwise it wouldn't compile, and it was causing new problems in different ways.

The fix wasnt all that hard, I moved the Renode app files to the gihub repo, merged, pushed, and lastly rewrote the compile script and also the launch script. I also had to tweak the .gitignore witch was a frightening experience for me but in the end I got it done.

https://lapse.hackclub.com/timelapse/XWEwpXMi7DrT 
https://lapse.hackclub.com/timelapse/eEOnstobjyAC
---
All lapses in one place (9 lapses) :
Setting up laptop :
https://lapse.hackclub.com/timelapse/IjtBbvyHWhr8
learning Renode :
https://lapse.hackclub.com/timelapse/3nuWk_uo0MtO
https://lapse.hackclub.com/timelapse/apcl5atXomEH
https://lapse.hackclub.com/timelapse/UcAXlp--94xe
Understanding the PCB :
https://lapse.hackclub.com/timelapse/7rRauqIhLzpM
https://lapse.hackclub.com/timelapse/YyGTl8KKhVPs
Github and Renode :
https://lapse.hackclub.com/timelapse/XWEwpXMi7DrT 
https://lapse.hackclub.com/timelapse/eEOnstobjyAC
Making the devlog :
https://lapse.hackclub.com/timelapse/ocI5iV70McJz
---
The end :)

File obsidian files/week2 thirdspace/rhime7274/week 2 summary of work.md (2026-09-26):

so this week was i feel very productive and alot less well scary than last week and im kinda getting into the groove of things tho grand (merekelene) is maybe not having it as easy with his time yet tho due to his like lots of theatre classes, so me and joao (monizjoao) have done some work, mainly making massive steps towards optimizing the time taken to complete the weeks hour quota, basically i crunched everything and so for joao its diff cuz he decides how he will spend his time obvi but for me if i work, so going chronologically we started the week and on monday i started getting more into modeling and started working towards getting our school chromebooks viable for coding, we can only do so much on lapse with timelapses of modeling till we get to the biggest part of the pre physical build being the software and firmware, currently grand is handling it but i wanna help him as he's sorta hit a brick wall with figuring out renode as its rather hard which is understandable yk, but yeah so for getting the chromebooks working for hackatime logging what i needed was to get either the linux dev environment aka crostini for the chromebooks done or make a list of applications because if they couldnt give me a settings change then the thing i knew would work is play store apps, but an asterisk on apps tho, but yeah so we would need brave because working without adblock is really really slow or maybe a better performance browser cuz chrome on the cbs is really slow, but yeah so then also Acode as its the only real ide i could use with hackatime tho it would take some fanagaling i believe, but yeah so then we need a way to use github as without it well its kinda useless if we do work and cant upload it or need to come home each time just to upload to our repo or pull from it, so i requested the apk version of termux made for x86 which is exactly what the chromebook would want and lastly obviously obsidian so we can write things nicely like i am right now, but the linux dev environment is way better cuz of the freedom, renode, kicad etc. this full list and like planning out what we would need, why, and how we would use it took me till thursday tho and wasnt sum i had down on monday, but on tuesday i did give in a full explanation and written request to use our chromebooks in class for work when we are done our class work as we are good students its not a big issue and we are pretty fast or i am, the teach was happy and i subsequently asked other teachers and the one to disagree was the portugese teacher though she gave a very understandable reason and its because my portugese isn't as good as it could be, its that way cuz im not too good at it and also im a foreigner, wednesday and thursday particularly wednesday joao and me were gonna log a bunch of time but we kinda flunked out because we were tired but its okay, next week will be much better the same way this week was better than the last, its all a matter of time till i adapt and im able to fully orchestrate this thing efficiently, speaking of orchestration earlier this week i accidently blew all my ai credits on glm 5.3 in opencode the day fucking mimo v2.6 release so i had to buy some again, i wont be making such a costly mistake again, anyways i should prolly cut to the chase and not write this like a personal diary, sorry bout that, anyways so i wrote up and gave my school admin a full well written and checked document for her to present to the DRAE for getting approval of our request, i will attach and image here for it but it will be censored as regardless of how much i already have publicly available i don't wanna accidentally put more and get into a sticky situation or sum.

![[censored doc p1.png]]

![[censored doc p2.png|591]]

so these are the documents for the DRAE or whoever was gonna be talked with, anyways so for the most part this week was just a shit ton of modeling, ill see if i have some screenshots, yeah i have some, here.

![[lenses and back.png]]

![[front and pcb.png]]

you can see the like display holders on the linear rods for ipd adjustment and the start of the lens assembly too, also on the back you can see its all nuked cuz the entire document died and we had to almost start for scratch (not really but it was pretty bad), anyways so idk what else to say, grand also has alibaba where he lives with tiny costs for shipping so we might make a route for getting him stuff and delivering it back home, but yeah i think thats it, so until next week.

made with love by oxy <3

lapse links:

https://lapse.hackclub.com/timelapse/OxHrwwc8bzsu
https://lapse.hackclub.com/timelapse/Qq2OVisVmfpj
https://lapse.hackclub.com/timelapse/tQGIr-x7XhRh
https://lapse.hackclub.com/timelapse/845iVJX_8Kzt
https://lapse.hackclub.com/timelapse/nfVtreNUa6ab
https://lapse.hackclub.com/timelapse/kR6qlZqq_LN0
https://lapse.hackclub.com/timelapse/WtiKOfRqt2if
https://lapse.hackclub.com/timelapse/Rw-4syWM3khl
https://lapse.hackclub.com/timelapse/JXnnkBSYRRAX (yes i drafted the doc on paper T-T)
https://lapse.hackclub.com/timelapse/EuZL446UGXsR
https://lapse.hackclub.com/timelapse/EuZL446UGXsR
https://lapse.hackclub.com/timelapse/fG8BKOUzBt_j
https://lapse.hackclub.com/timelapse/ycKDxk1f7pq6 (the one i wrote this during)

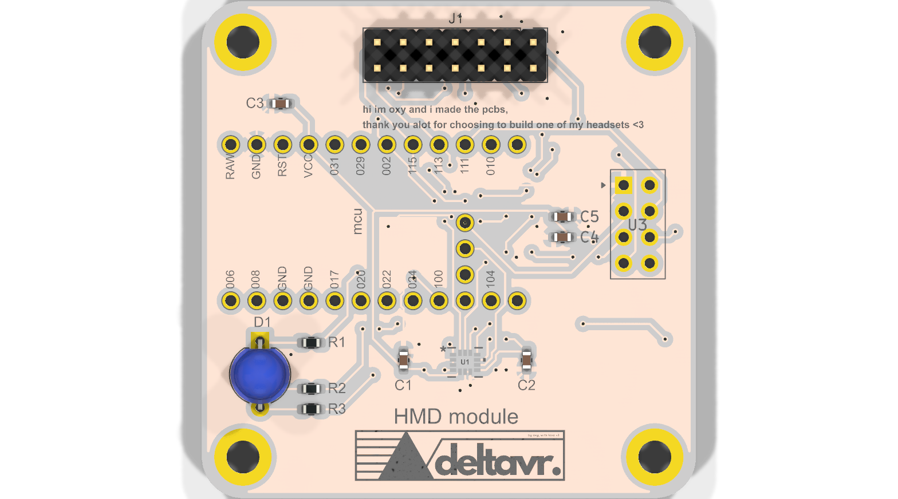
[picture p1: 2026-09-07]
release v1.0.0/renders/hmd-top.png

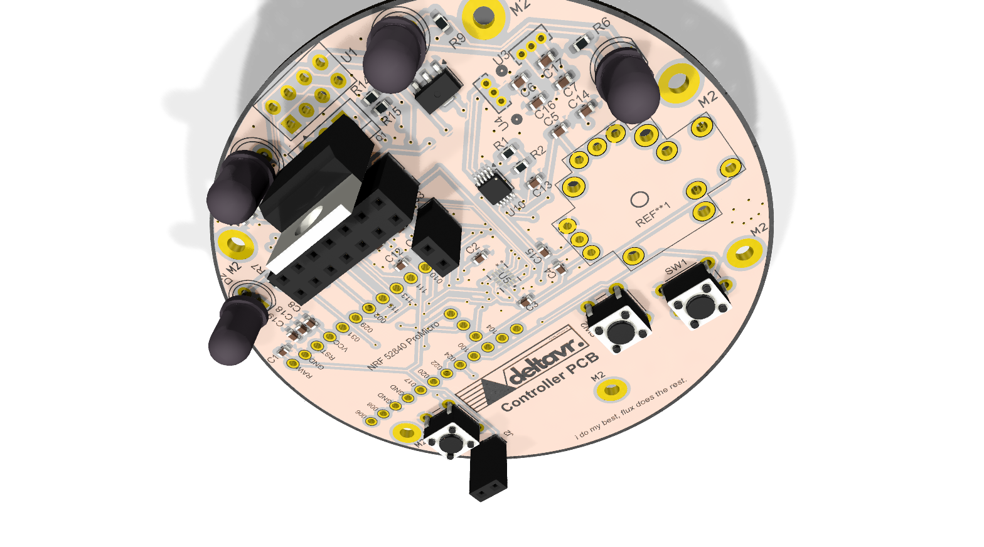
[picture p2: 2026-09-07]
release v1.0.0/renders/controller-r-iso.png

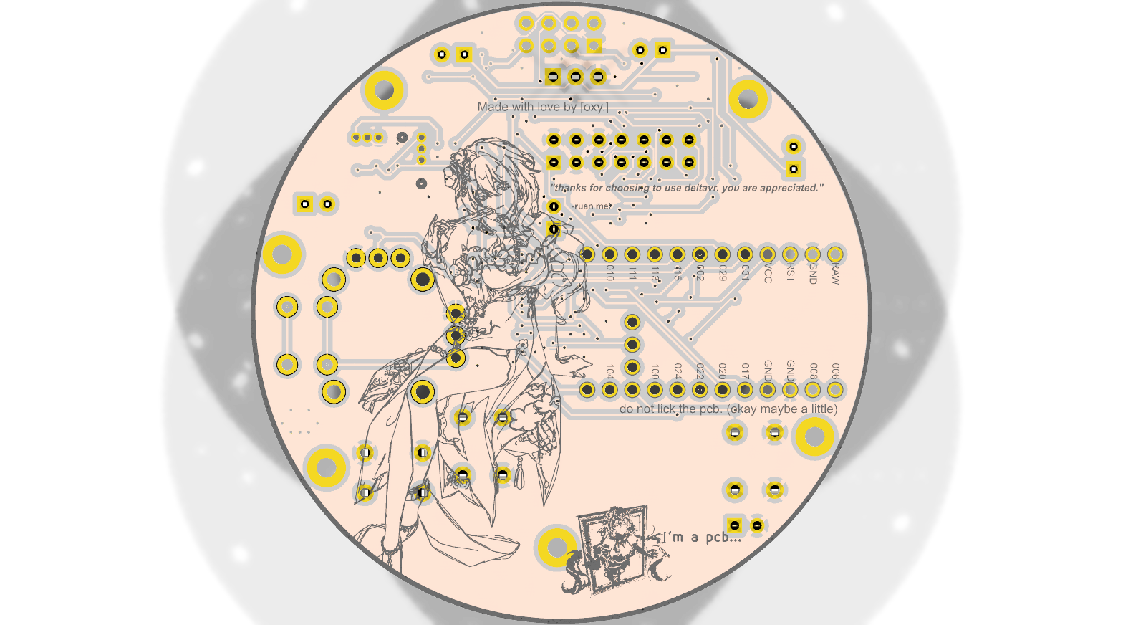
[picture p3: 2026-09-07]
release v1.0.0/renders/controller-r-bottom.png

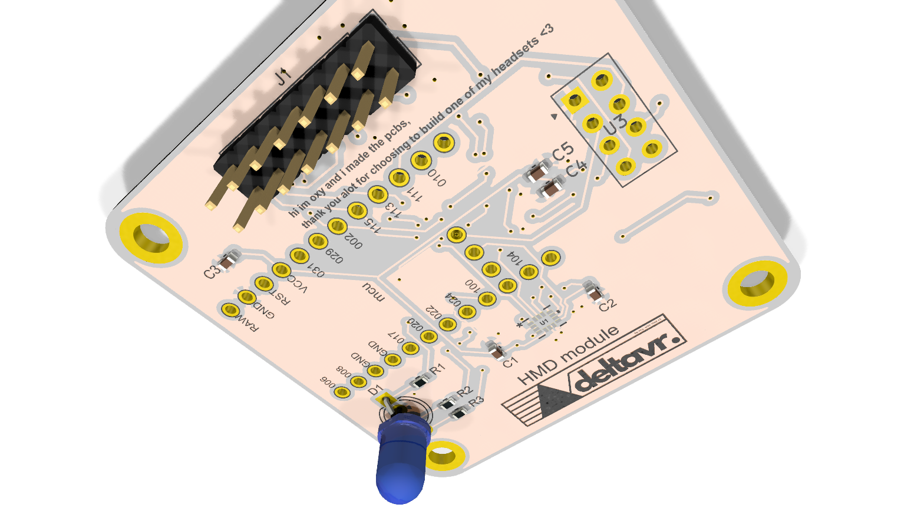
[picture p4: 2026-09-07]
release v1.0.0/renders/hmd-iso.png

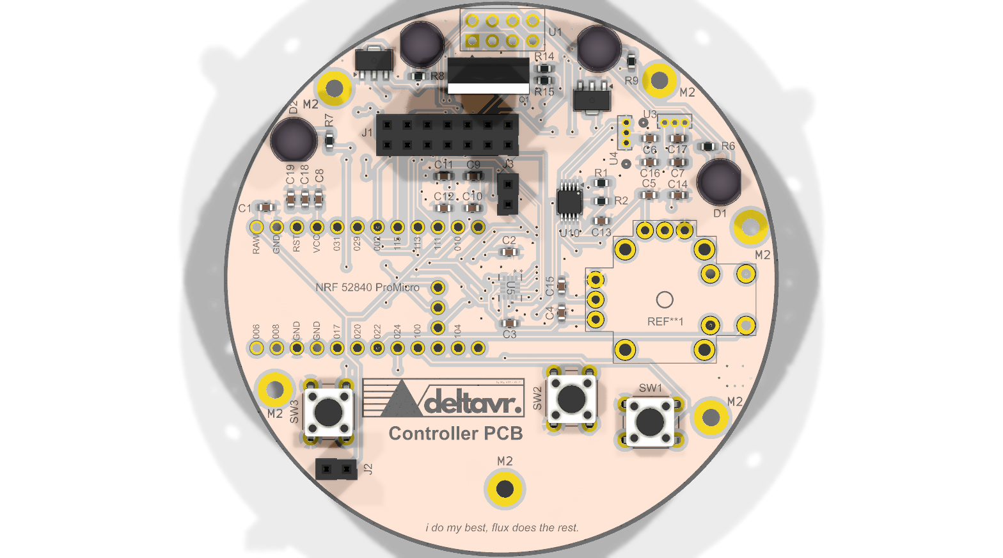
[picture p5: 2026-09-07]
release v1.0.0/renders/controller-r-top.png

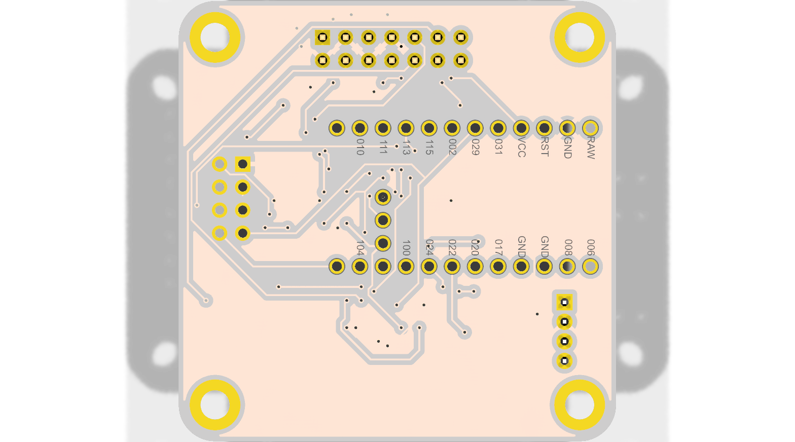
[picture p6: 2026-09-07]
release v1.0.0/renders/hmd-bottom.png

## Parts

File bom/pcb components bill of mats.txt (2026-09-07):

sorry this is written informally its just like the parts you'll have to source, i recommend and am using Alibaba and AliExpress
so this is like for everything like both controllers and the hmd:

3x LSM6DSV family imus (dont get a breakout board, its smd, get the LGA-14 ones)
3x NRF24L01+ PA + LNA modules (the ones with the antennas that are through-hole boards)
3x NRF52840 Pro Micro boards (the like nicenano v2.0 compatible ones)
1x RAGB LED 5mm
1x smd resistor book 0603 (for all the resistors on the board)
1x smd capacitor book 0603 (for all the caps on the board, except some)
4x ht7333 (sot-89 smd ones)
2x ADS1115 (msop-10)
2x 3.7v 103048 1500mAh LiPo
8x 850nm 5mm LEDs (get 100ma max current ones that work at 1.4v to 1.6v)
2x IRLZ44N TO-220 mosfets
6x  6x6x4.3MM 4PIN G89 Tactile Tact Push Buttons
13x 10uF 25V X7R 0603 capacitors
2x ginfull tmr PS5 replacement joysticks (make sure they are uh with the button lol but yeah)
4x SS49E hall effect sensors

of course a reminder this is for just the pcbs not the entire headset, youd still need for the headset well the like housing, screen, cameras etc.

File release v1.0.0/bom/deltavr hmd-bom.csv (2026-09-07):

Reference | Value | Footprint
C1 | 100nF | Capacitor_SMD:C_0603_1608Metric_Pad1.08x0.95mm_HandSolder
C2 | 100nF | Capacitor_SMD:C_0603_1608Metric_Pad1.08x0.95mm_HandSolder
C3 | 100nF | Capacitor_SMD:C_0603_1608Metric_Pad1.08x0.95mm_HandSolder
C4 | 10uF | Capacitor_SMD:C_0603_1608Metric_Pad1.08x0.95mm_HandSolder
C5 | 100nF | Capacitor_SMD:C_0603_1608Metric_Pad1.08x0.95mm_HandSolder
D1 | LED_RAGB | LED_THT:LED_D5.0mm-4_RGB_Wide_Pins
J1 | Conn_02x07_Top_Bottom | Connector_PinHeader_2.54mm:PinHeader_2x07_P2.54mm_Vertical
R1 | 1k | Resistor_SMD:R_0603_1608Metric_Pad0.98x0.95mm_HandSolder
R2 | 1k | Resistor_SMD:R_0603_1608Metric_Pad0.98x0.95mm_HandSolder
R3 | 1k | Resistor_SMD:R_0603_1608Metric_Pad0.98x0.95mm_HandSolder
U1 | LSM6DSVTR | footprints:LGA14-L_2P59X3P1X0P5_STM-M
U2 | nice_nano | nicenano footprint:nice_nano
U3 | NRF24L01_Breakout | RF_Module:nRF24L01_Breakout

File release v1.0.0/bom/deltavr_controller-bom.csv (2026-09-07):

Reference | Value | Footprint
C1 | 10uF | Capacitor_SMD:C_0603_1608Metric_Pad1.08x0.95mm_HandSolder
C2 | 100nf | Capacitor_SMD:C_0603_1608Metric_Pad1.08x0.95mm_HandSolder
C3 | 100nf | Capacitor_SMD:C_0603_1608Metric_Pad1.08x0.95mm_HandSolder
C4 | 100nf | Capacitor_SMD:C_0603_1608Metric_Pad1.08x0.95mm_HandSolder
C5 | 100nf | Capacitor_SMD:C_0603_1608Metric_Pad1.08x0.95mm_HandSolder
C6 | 100nf | Capacitor_SMD:C_0603_1608Metric_Pad1.08x0.95mm_HandSolder
C7 | 100nf | Capacitor_SMD:C_0603_1608Metric_Pad1.08x0.95mm_HandSolder
C8 | 100nf | Capacitor_SMD:C_0603_1608Metric_Pad1.08x0.95mm_HandSolder
C9 | 10uF | Capacitor_SMD:C_0603_1608Metric_Pad1.08x0.95mm_HandSolder
C10 | 10uF | Capacitor_SMD:C_0603_1608Metric_Pad1.08x0.95mm_HandSolder
C11 | 10uF | Capacitor_SMD:C_0603_1608Metric_Pad1.08x0.95mm_HandSolder
C12 | 10uF | Capacitor_SMD:C_0603_1608Metric_Pad1.08x0.95mm_HandSolder
C13 | 100nf | Capacitor_SMD:C_0603_1608Metric_Pad1.08x0.95mm_HandSolder
C14 | 100nf | Capacitor_SMD:C_0603_1608Metric_Pad1.08x0.95mm_HandSolder
C15 | 100nf | Capacitor_SMD:C_0603_1608Metric_Pad1.08x0.95mm_HandSolder
C16 | 100nf | Capacitor_SMD:C_0603_1608Metric_Pad1.08x0.95mm_HandSolder
C17 | 100nf | Capacitor_SMD:C_0603_1608Metric_Pad1.08x0.95mm_HandSolder
C18 | 10uF | Capacitor_SMD:C_0603_1608Metric_Pad1.08x0.95mm_HandSolder
C19 | 100nF | Capacitor_SMD:C_0603_1608Metric_Pad1.08x0.95mm_HandSolder
D1 | 850nm | LED_THT:LED_D5.0mm_IRGrey
D2 | 850nm | LED_THT:LED_D5.0mm_IRGrey
D3 | 850nm | LED_THT:LED_D5.0mm_IRGrey
D4 | 850nm | LED_THT:LED_D5.0mm_IRGrey
J1 | debug | Connector_PinSocket_2.54mm:PinSocket_2x07_P2.54mm_Vertical
J2 | battery pins 3.7v | Connector_PinSocket_2.54mm:PinSocket_1x02_P2.54mm_Vertical
J3 | test 3.3v pins | Connector_PinSocket_2.54mm:PinSocket_1x02_P2.54mm_Vertical
Q1 | IRLZ44N | Package_TO_SOT_THT:TO-220-3_Vertical
R1 | 4.7kΩ | Resistor_SMD:R_0603_1608Metric_Pad0.98x0.95mm_HandSolder
R2 | 4.7kΩ | Resistor_SMD:R_0603_1608Metric_Pad0.98x0.95mm_HandSolder
R6 | 15Ω | Resistor_SMD:R_0603_1608Metric_Pad0.98x0.95mm_HandSolder
R7 | 15Ω | Resistor_SMD:R_0603_1608Metric_Pad0.98x0.95mm_HandSolder
R8 | 15Ω | Resistor_SMD:R_0603_1608Metric_Pad0.98x0.95mm_HandSolder
R9 | 15Ω | Resistor_SMD:R_0603_1608Metric_Pad0.98x0.95mm_HandSolder
R14 | 100KΩ | Resistor_SMD:R_0603_1608Metric_Pad0.98x0.95mm_HandSolder
R15 | 100Ω | Resistor_SMD:R_0603_1608Metric_Pad0.98x0.95mm_HandSolder
REF**1 | PS5 | thumbstick footprint:Joystick
SW1 | SW_Push | Button_Switch_THT:SW_PUSH_6mm_H4.3mm
SW2 | SW_Push | Button_Switch_THT:SW_PUSH_6mm_H4.3mm
SW3 | SW_Push | Button_Switch_THT:SW_PUSH_6mm_H4.3mm
U1 | NRF24L01_Breakout | RF_Module:nRF24L01_Breakout
U2 | nice_nano | nicenano footprint:nice_nano
U3 | SS49E | ss49e footprint:SEN3_SS49E_HNW
U4 | SS49E | ss49e footprint:SEN3_SS49E_HNW
U5 | LSM6DSVTR | lsm6dsvtr footprint:LGA14-L_2P59X3P1X0P5_STM-M
U8 | HT7333 | Package_TO_SOT_SMD:SOT-89-3
U9 | HT7333 | Package_TO_SOT_SMD:SOT-89-3
U10 | ADS1115IDGS | Package_SO:TSSOP-10_3x3mm_P0.5mm

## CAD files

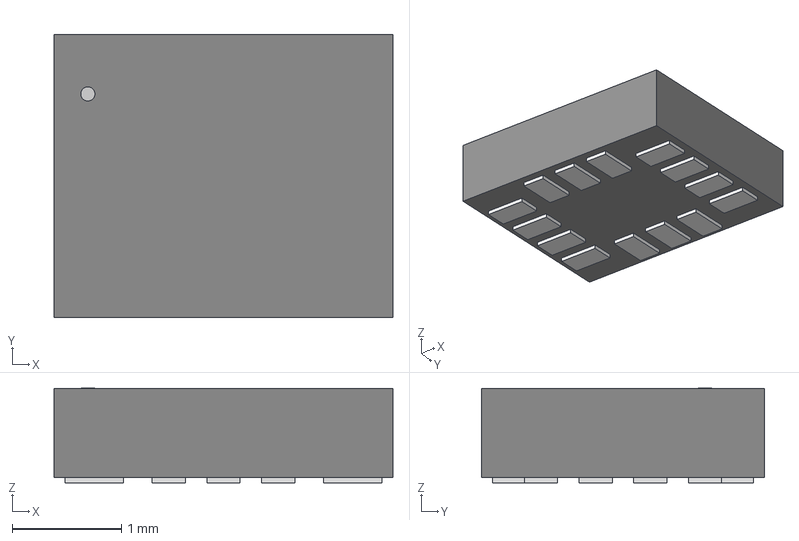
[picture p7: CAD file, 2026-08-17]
kicad libaries/lsm6dsvtr/LGA14-L_2p59x3P1x0P5_STM.step
3.10 x 2.59 x 0.866 mm

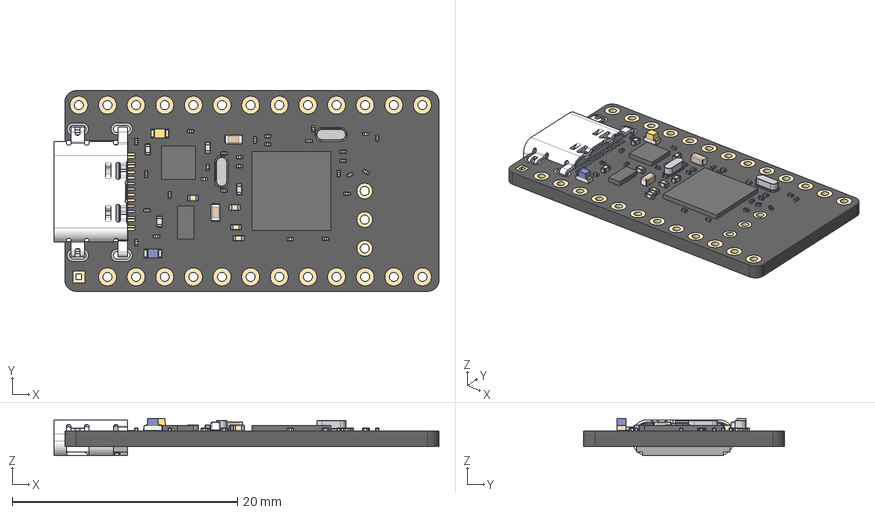
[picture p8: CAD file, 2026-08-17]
kicad libaries/nicenano stuff/nicenanomodelstep/nice!nano v2.step
34.2 x 17.8 x 3.28 mm
nice!nano v1.0
SSOP16
LED_0603_1608Metric_ON
LED_0603_1608Metric_ON_1
Crystal Oscillator
Crystal Oscillator_1
usb4520-03-0-a_1
C0201 x 21
C0402 x 8
C0201_1 x 7

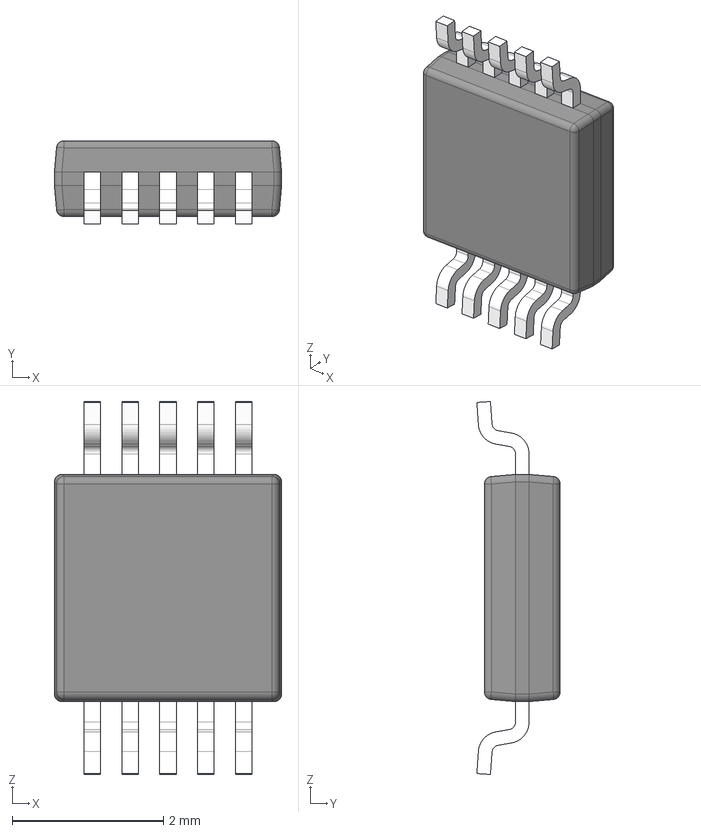
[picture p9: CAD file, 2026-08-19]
kicad libaries/ul_ADS1115IDGSR/DGS0010A.stp
3.00 x 1.10 x 4.93 mm
BODY-SO
LEAD-SO x 10
PIN1-ID

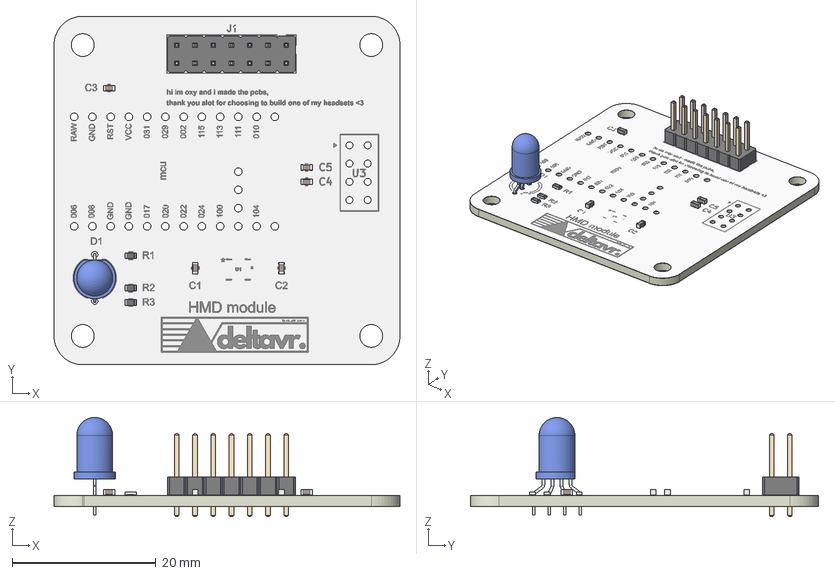
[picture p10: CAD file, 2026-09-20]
kicad/deltavr hmd.step
48.2 x 48.5 x 13.8 mm
C_0603_1608Metric x 5
R_0603_1608Metric x 3
PinHeader_2x07_P254mm_Vertical
LED_D5.0mm-4_RGB_Wide_Pins
del1A48_silkscreen x 2
del1A48_soldermask x 2
del1A48_PCB

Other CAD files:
kicad/deltavr hmd.stl

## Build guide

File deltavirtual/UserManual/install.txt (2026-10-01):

Install
1 - go to this link
	https://github.com/renode/renode

2 - (windows) scroll down and click on the
	renode-latest.setup.exe

3 - open the downloaded file and MAKE SURE to select "add to PATH"

4 - proceed with install as with any other exe

5 - open command promt and type 
	renode

6 - to make sure that everything works properly, run this command
	include @scripts/single-node/quark_c1000.resc

if you encounter any problems ask - merekelene

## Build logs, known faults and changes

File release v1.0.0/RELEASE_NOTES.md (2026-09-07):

# deltavr v1.0.0 — PCBs officially done

first fabrication-ready release of the deltavr pcbs. everything here is everything you need to build both boards.

## what's in this release

| asset | what it is |
|---|---|
| `deltavr-hmd-gerbers.zip` | HMD board gerbers + Excellon drill + pick-and-place, JLCPCB layer naming |
| `deltavr-controller-r-gerbers.zip` | right-hand controller board gerbers + drill + PnP, JLCPCB naming |
| `schematics/` | PDF schematics for both boards |
| `bom/` | CSV BOMs, interactive HTML BOMs (open in any browser), + informal parts-sourcing list |
| `renders/` | 3D renders, top/bottom/iso per board |

## fabricating

- fab tested against JLCPCB rules (2-layer, 1.6mm FR-4). upload the 7 gerbers from a zip, extensions are already JLCPCB layer naming so it auto-detects.
- DRC: 0 errors, 0 unconnected nets on both boards (fresh kicad-cli run against the committed designs).
- **left-hand controller**: only the right board is shipped. copy `kicad controller R/`, open the pcb, select everything and mirror about the Y axis — the design is symmetric so it just works.

## sourcing

see `bom/pcb components bill of mats.txt` for the informal full-build parts list (covers HMD + both controllers). everything is Alibaba/AliExpress friendly.

## boards

- **HMD** (48x49mm): nRF52840 Pro Micro (nice_nano) + nRF24L01+ PA/LNA + LSM6DSVTR IMU + debug header exposing every pin + silk art.
- **controller R** (70x70mm round): ginfull TMR thumbstick via ADS1115, 2x SS49E hall triggers, 3x tact, nRF24L01+ radio module for off-board install, IRLZ44N for rumble. art on the silk.

no firmware yet — tracking/display stack is next.

known cosmetic DRC warnings (silk-over-copper on the art, text size flags, isolated islands on B.Cu) are documented and accepted; none affect fab.

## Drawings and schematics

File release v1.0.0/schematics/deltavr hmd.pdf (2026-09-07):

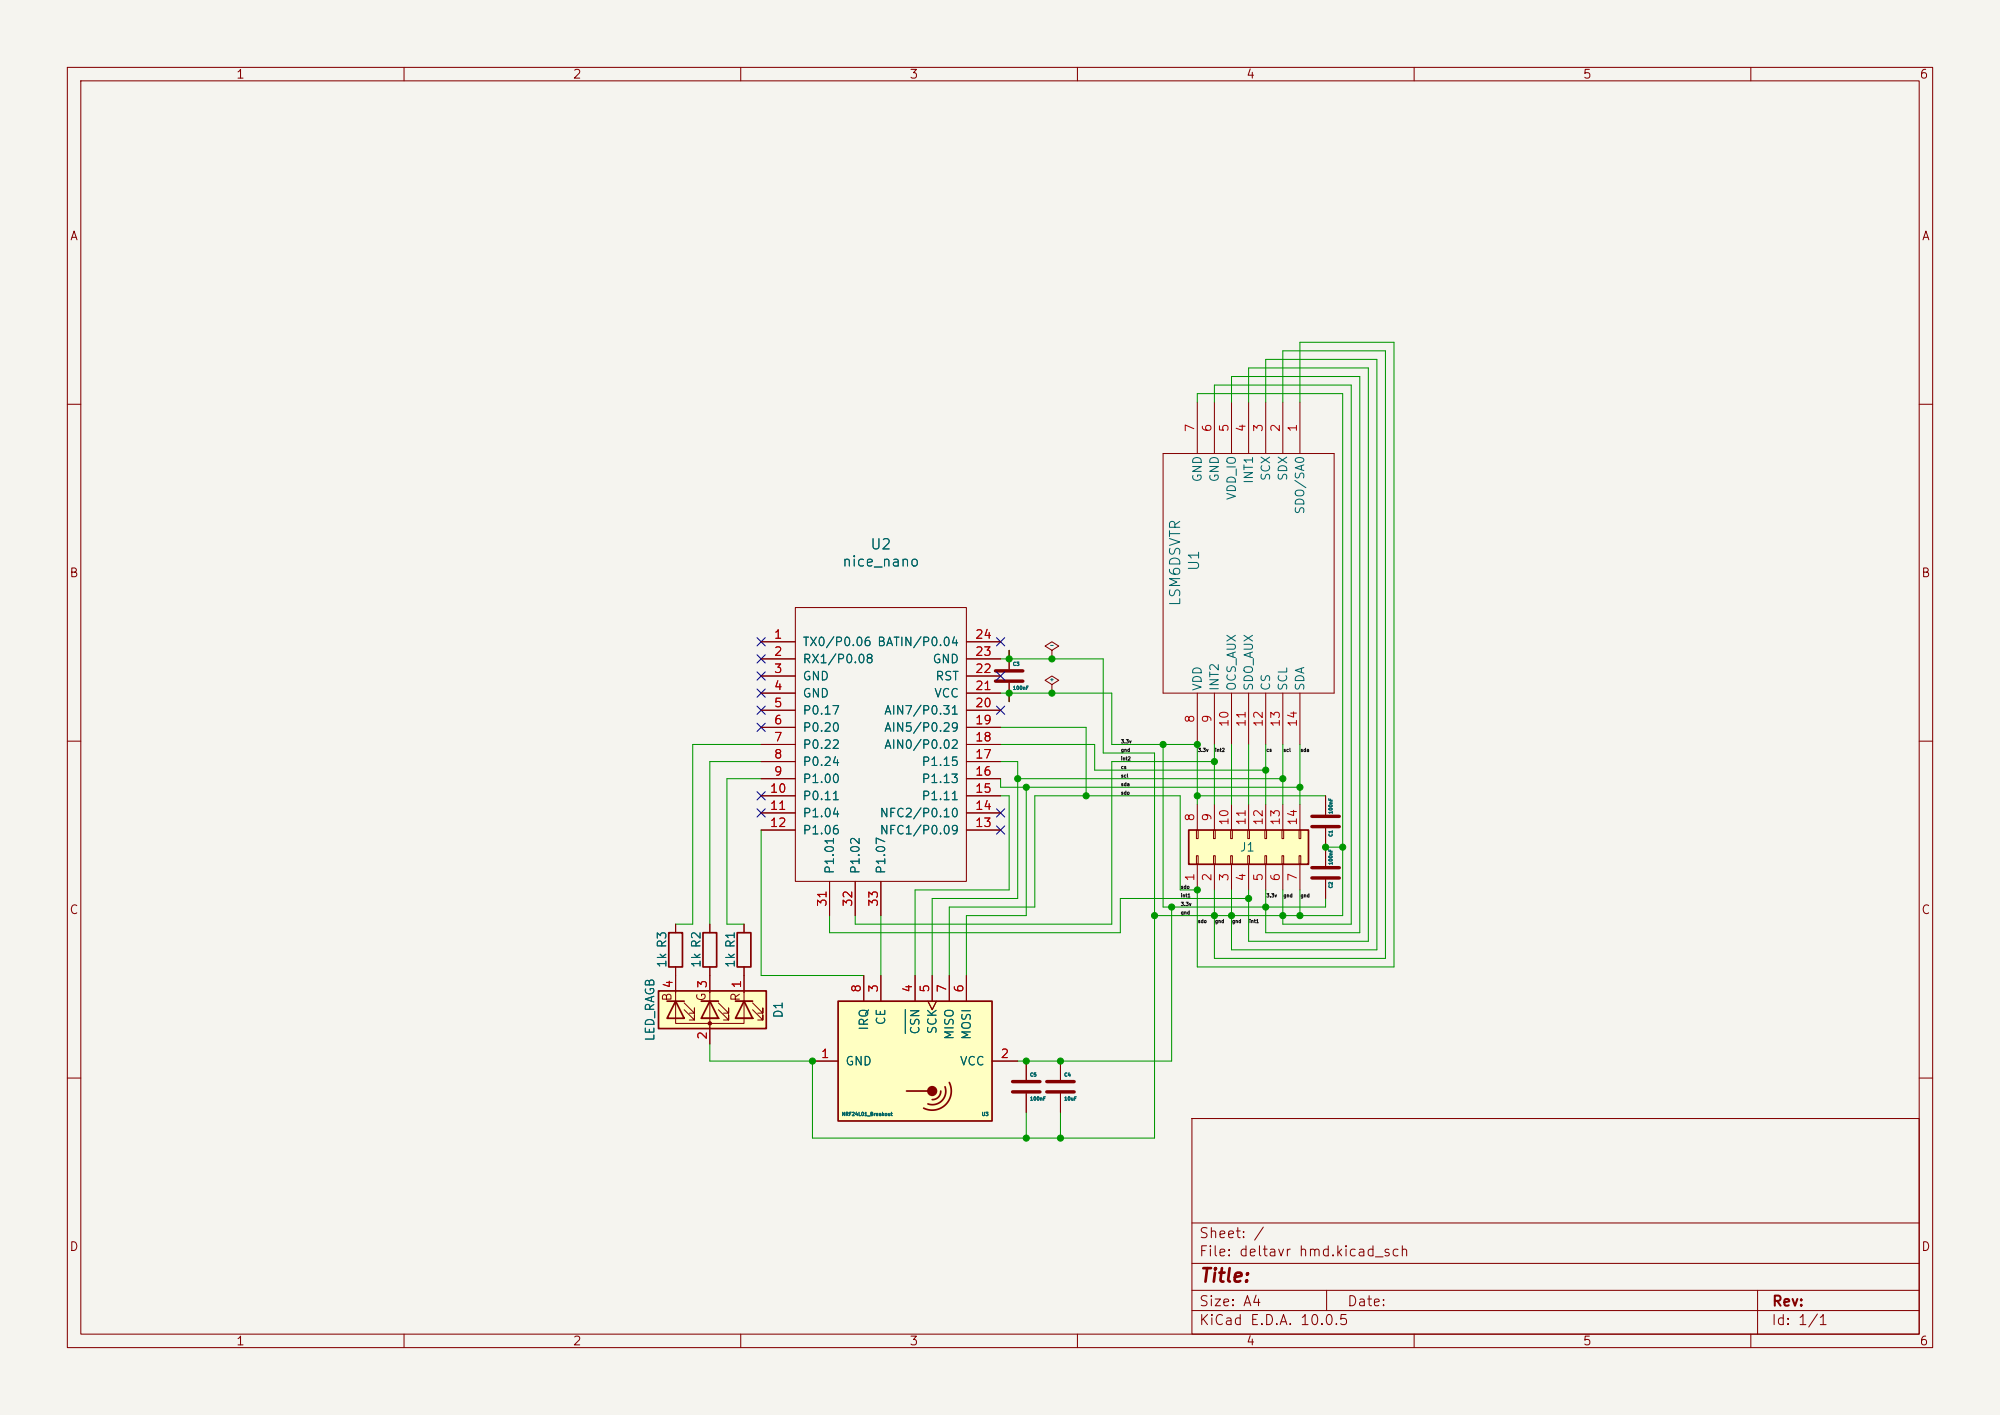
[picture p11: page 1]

gnd

Size: A4 | Rev:
KiCad E.D.A. 10.0.5 | Id: 1/1

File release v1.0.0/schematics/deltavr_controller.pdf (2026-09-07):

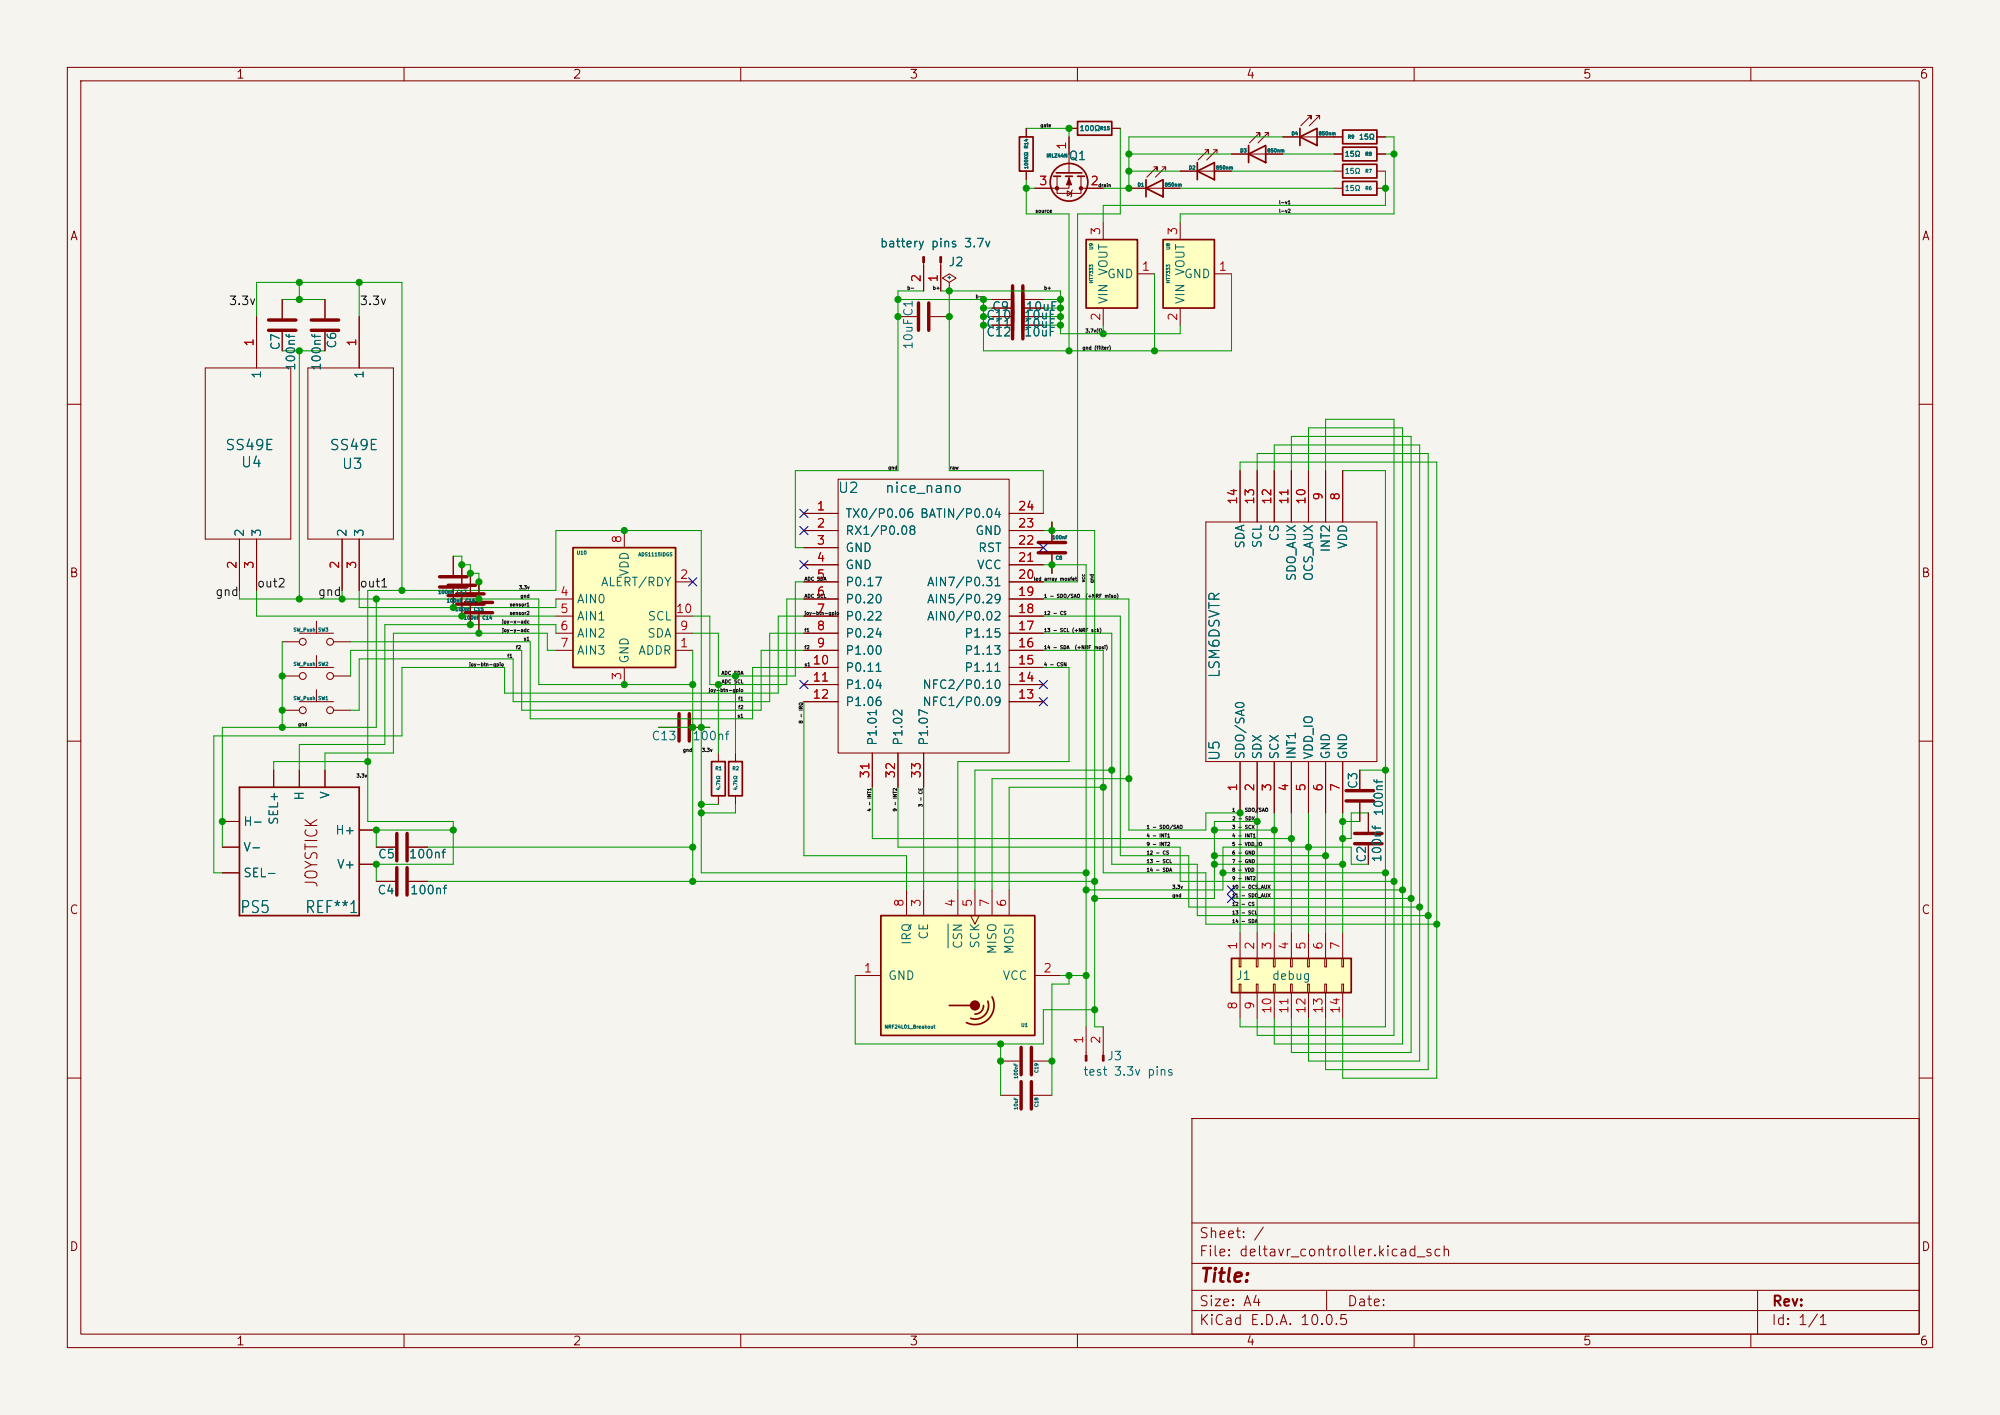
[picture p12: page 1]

9 - INT2 | 5 - VDD_IO

Size: A4 | Rev:
KiCad E.D.A. 10.0.5 | Id: 1/1

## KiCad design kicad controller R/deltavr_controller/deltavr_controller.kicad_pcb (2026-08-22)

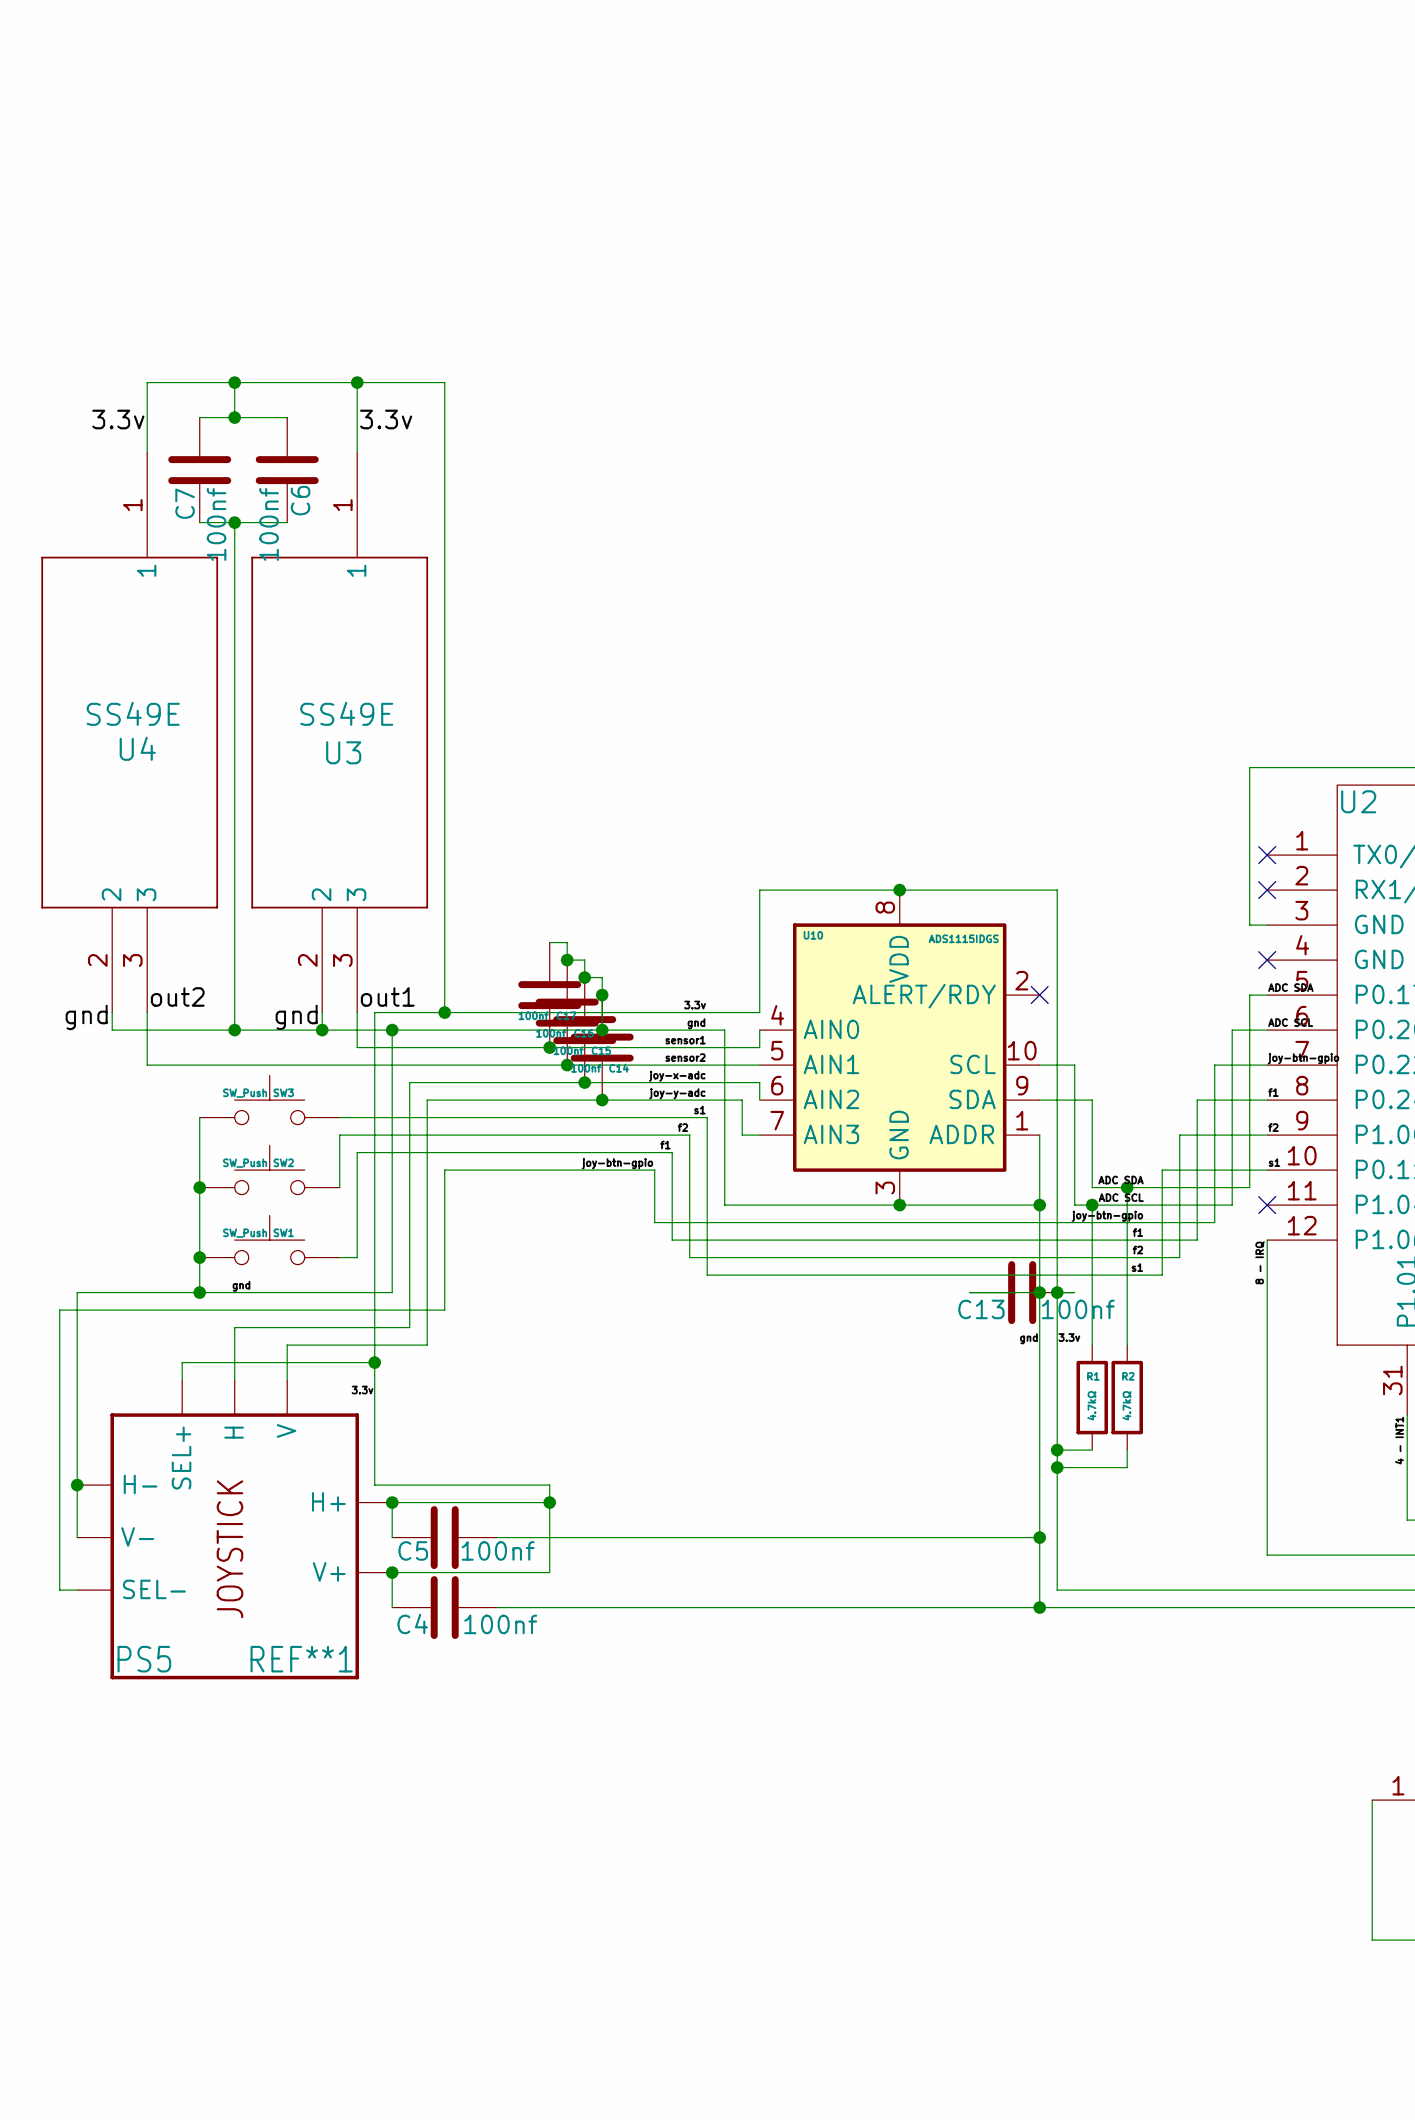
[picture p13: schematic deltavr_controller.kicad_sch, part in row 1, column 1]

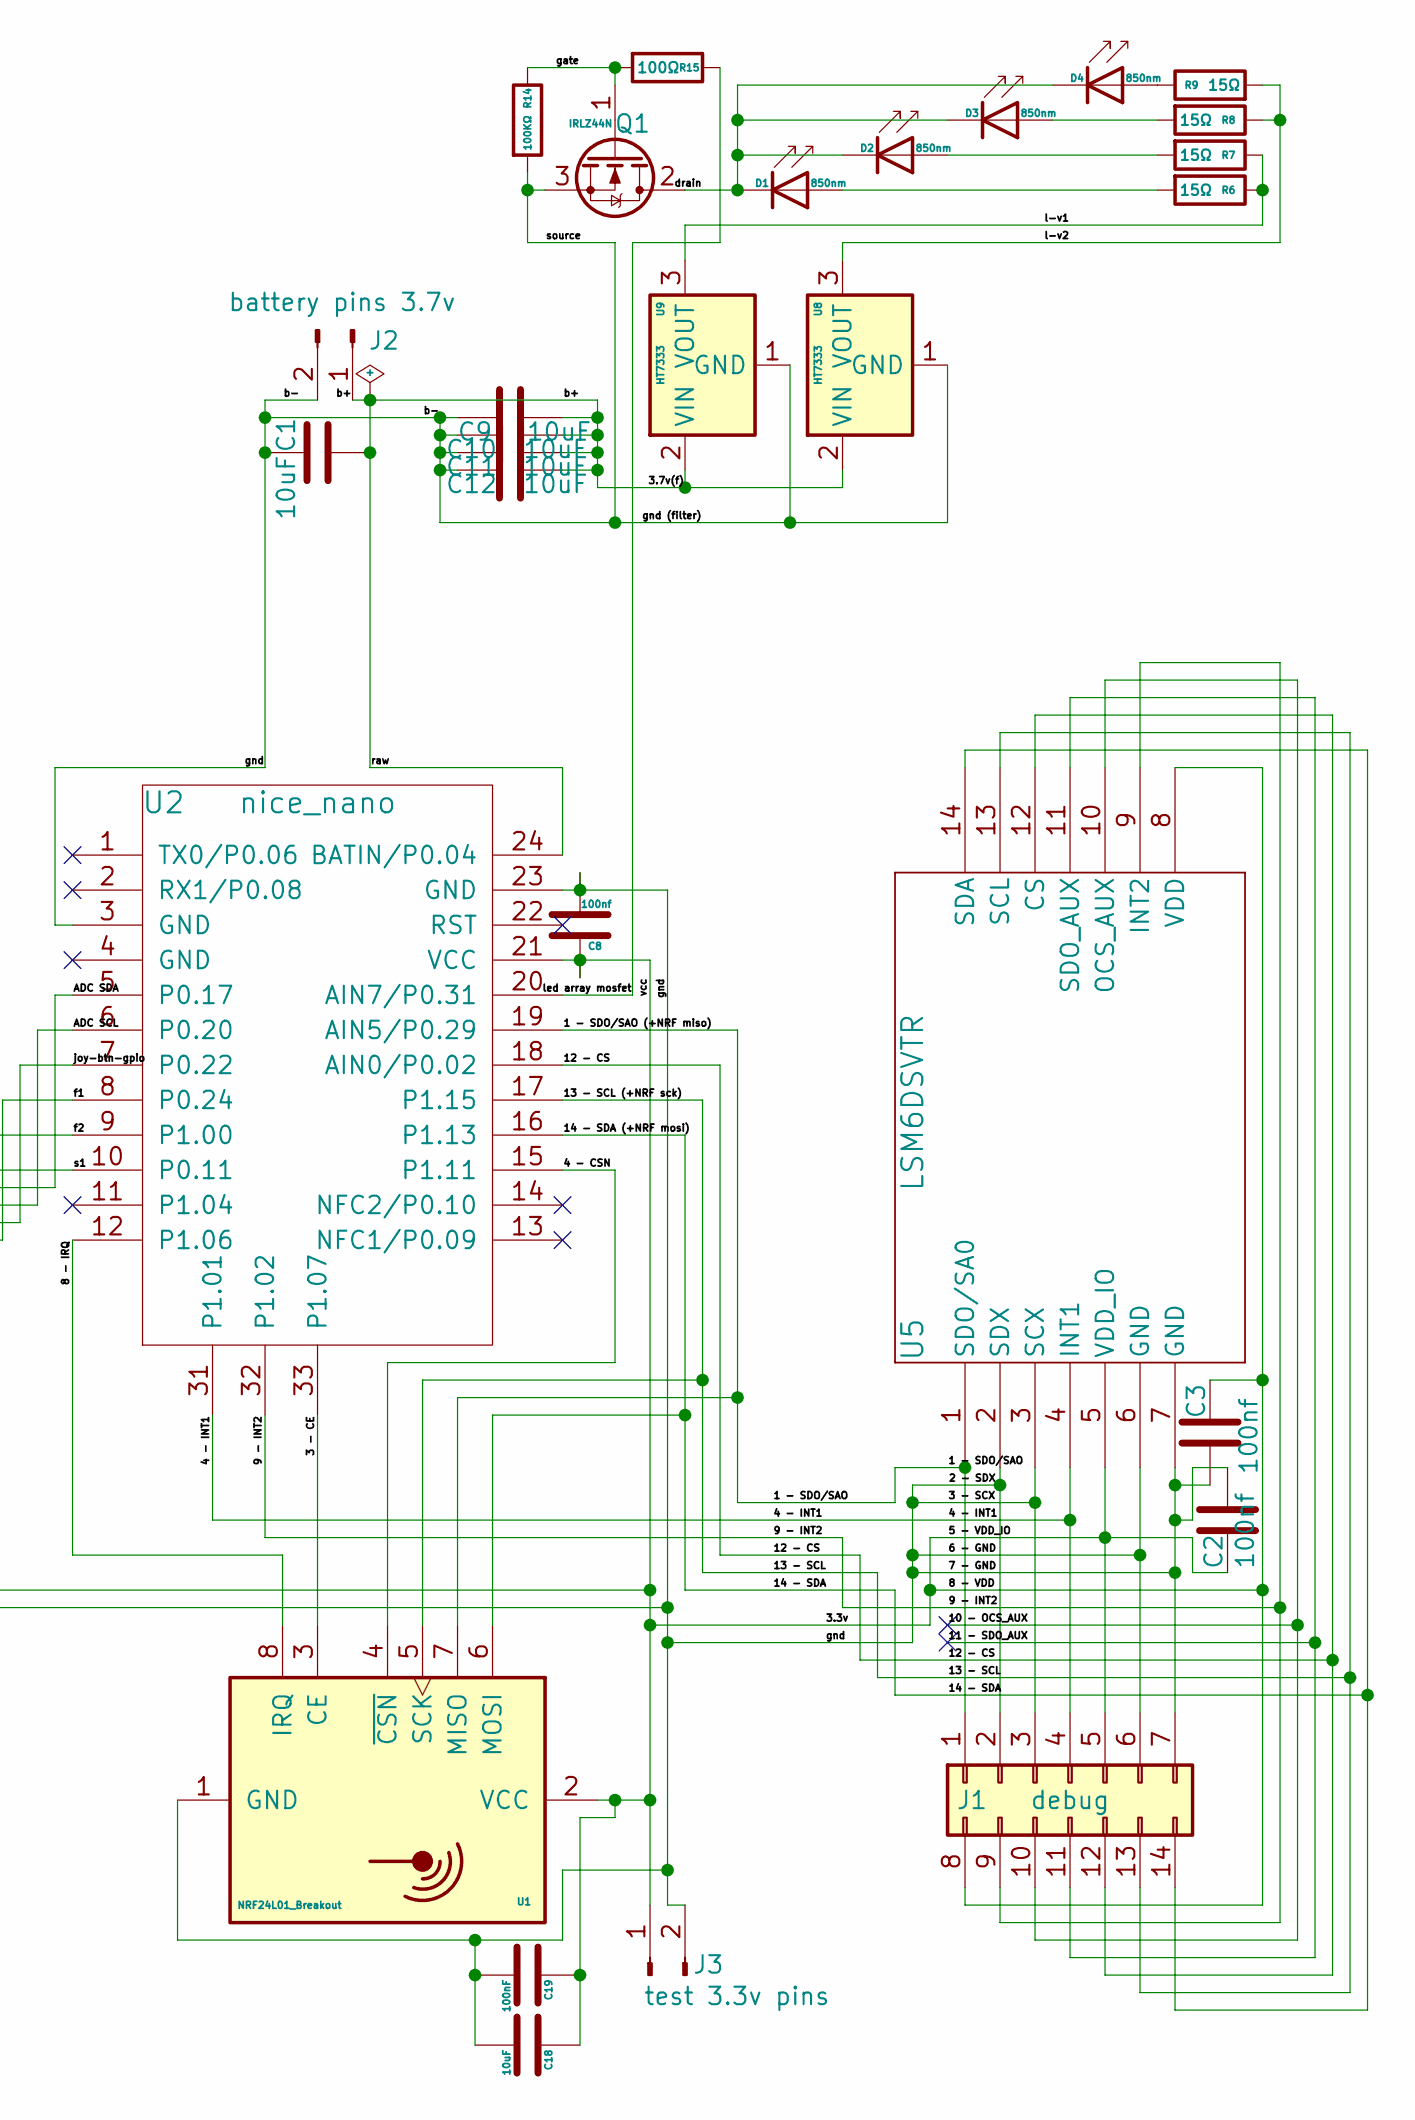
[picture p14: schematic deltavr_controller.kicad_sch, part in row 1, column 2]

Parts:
C1, C9, C10, C11, C12, C18: 10uF; C_0603_1608Metric_Pad1.08x0.95mm_HandSolder
C2, C3, C4, C5, C6, C7, C8, C13, C14, C15, C16, C17: 100nf; C_0603_1608Metric_Pad1.08x0.95mm_HandSolder
C19: 100nF; C_0603_1608Metric_Pad1.08x0.95mm_HandSolder
D1, D2, D3, D4: 850nm; LED_D5.0mm_IRGrey
J1: debug; PinSocket_2x07_P2.54mm_Vertical
J2: battery pins 3.7v; PinSocket_1x02_P2.54mm_Vertical
J3: test 3.3v pins; PinSocket_1x02_P2.54mm_Vertical
Q1: IRLZ44N; TO-220-3_Vertical
R1, R2: 4.7kΩ; R_0603_1608Metric_Pad0.98x0.95mm_HandSolder
R6, R7, R8, R9: 15Ω; R_0603_1608Metric_Pad0.98x0.95mm_HandSolder
R14: 100KΩ; R_0603_1608Metric_Pad0.98x0.95mm_HandSolder
R15: 100Ω; R_0603_1608Metric_Pad0.98x0.95mm_HandSolder
REF**1: PS5; Joystick
SW1, SW2, SW3: SW_Push; SW_PUSH_6mm_H4.3mm
U1: NRF24L01_Breakout; nRF24L01_Breakout
U2: nice_nano
U3, U4: SS49E; SEN3_SS49E_HNW
U5: LSM6DSVTR; LGA14-L_2P59X3P1X0P5_STM-M
U8, U9: HT7333; SOT-89-3
U10: ADS1115IDGS; TSSOP-10_3x3mm_P0.5mm

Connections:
/1 - SDO/SAO: J1.1, U1.7 (MISO), U2.19 (AIN5/P0.29), U5.1 (SDO/SA0)
/2 - SDX: C1.1, C2.2, C3.1, C4.2, C5.2, C6.2, C7.2, C8.1, C9.1, C10.1, C11.1, C12.1, C13.1, C14.2, C15.2, C16.2, C17.2, C18.2, C19.2, J1.2, J1.3, J1.6, J1.7, J2.2, J3.2, Q1.3 (S), R14.2, REF**1.1 (H-), REF**1.1' (V-), SW1.1, SW2.1, SW3.1, U1.1 (GND), U2.3 (GND), U2.23 (GND), U3.2, U4.2, U5.2 (SDX), U5.3 (SCX), U5.6 (GND), U5.7 (GND), U8.1 (GND), U9.1 (GND), U10.1 (ADDR), U10.3 (GND)
/3 - CE: U1.3 (CE), U2.33 (P1.07)
/3.3v: C2.1, C3.2, C4.1, C5.1, C6.1, C7.1, C8.2, C13.2, C18.1, C19.1, J1.5, J1.8, J3.1, R1.2, R2.2, REF**1.3 (H+), REF**1.3' (V+), REF**1.a (SEL+), U1.2 (VCC), U2.21 (VCC), U3.1, U4.1, U5.5 (VDD_IO), U5.8 (VDD), U10.8 (VDD)
/3.7v(f): C1.2, C9.2, C10.2, C11.2, C12.2, J2.1, U2.24 (BATIN/P0.04), U8.2 (VIN), U9.2 (VIN)
/4 - CSN: U1.4 (~CSN), U2.15 (P1.11)
/4 - INT1: J1.4, U2.31 (P1.01), U5.4 (INT1)
/8 - IRQ: U1.8 (IRQ), U2.12 (P1.06)
/9 - INT2: J1.9, U2.32 (P1.02), U5.9 (INT2)
/10 - OCS_AUX: J1.10, U5.10 (OCS_AUX)
/11 - SDO_AUX: J1.11, U5.11 (SDO_AUX)
/12 - CS: J1.12, U2.18 (AIN0/P0.02), U5.12 (CS)
/13 - SCL: J1.13, U1.5 (SCK), U2.17 (P1.15), U5.13 (SCL)
/14 - SDA: J1.14, U1.6 (MOSI), U2.16 (P1.13), U5.14 (SDA)
/ADC SCL: R1.1, U2.6 (P0.20), U10.10 (SCL)
/ADC SDA: R2.1, U2.5 (P0.17), U10.9 (SDA)
/drain: D1.1 (K), D2.1 (K), D3.1 (K), D4.1 (K), Q1.2 (D)
/f1: SW1.2, U2.8 (P0.24)
/f2: SW2.2, U2.9 (P1.00)
/gate: Q1.1 (G), R14.1, R15.2
/joy-btn-gpio: REF**1.c (SEL-), U2.7 (P0.22)
/joy-x-adc: C15.1, REF**1.2 (H), U10.6 (AIN2)
/joy-y-adc: C14.1, REF**1.2' (V), U10.7 (AIN3)
/l-v1: R6.1, R7.1, U9.3 (VOUT)
/l-v2: R8.1, R9.2, U8.3 (VOUT)
/led array mosfet: R15.1, U2.20 (AIN7/P0.31)
/out1: C17.1, U3.3, U10.4 (AIN0)
/out2: C16.1, U4.3, U10.5 (AIN1)
/s1: SW3.2, U2.10 (P0.11)
unnamed: D1.2 (A), R6.2
unnamed: D2.2 (A), R7.2
unnamed: D3.2 (A), R8.2
unnamed: D4.2 (A), R9.1

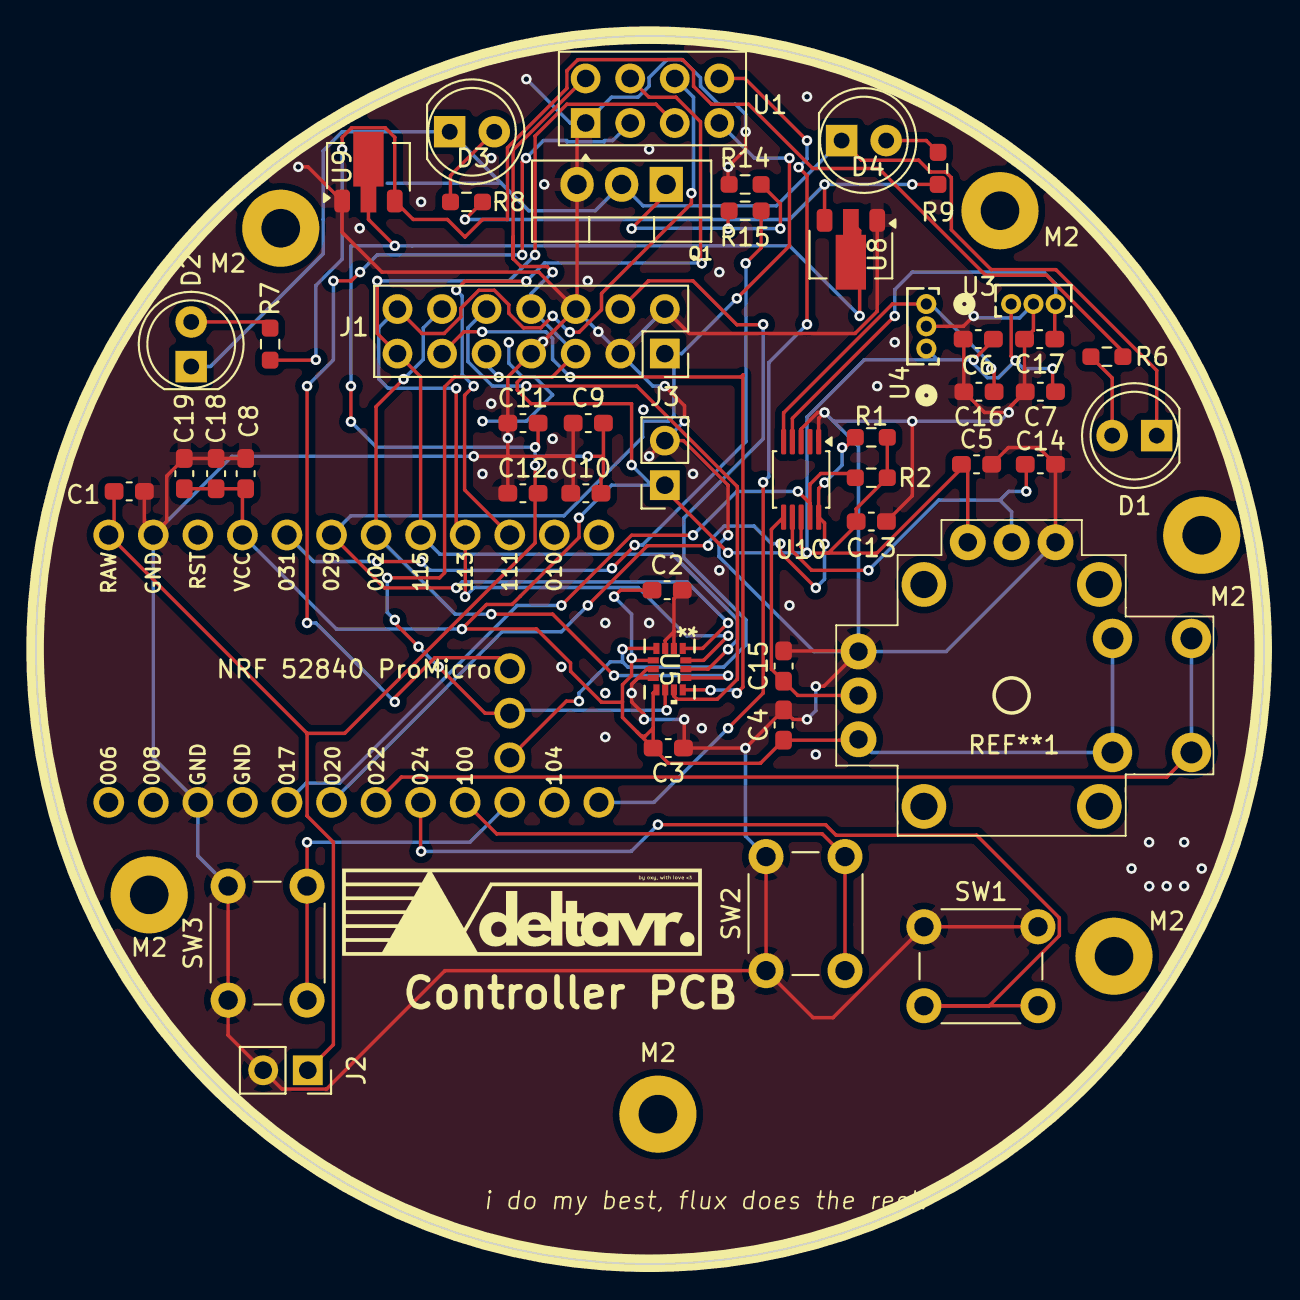
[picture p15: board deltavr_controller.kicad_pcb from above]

Board: 2 copper layers, 70.0 x 70.0 mm, 52 parts (0 on the bottom side), 32 nets.

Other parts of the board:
M2, M2#2, M2#3, M2#4, M2#5, M2#6: MountingHole_2.2mm_M2_Pad

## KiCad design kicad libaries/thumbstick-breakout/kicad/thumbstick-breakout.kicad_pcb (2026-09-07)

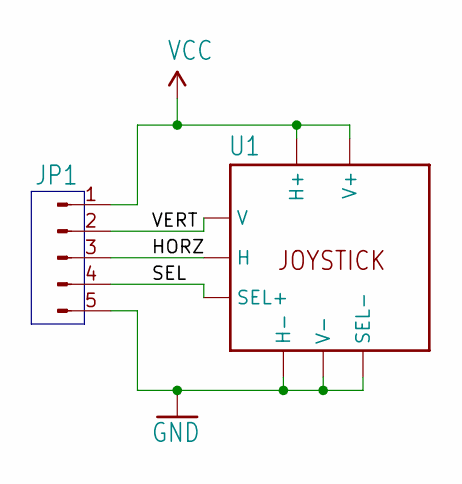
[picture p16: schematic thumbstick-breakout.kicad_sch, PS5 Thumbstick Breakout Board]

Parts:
JP1: 1x05
U1: Joystick

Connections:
/HORZ: JP1.3, U1.2 (H)
/SEL: JP1.4, U1.a (SEL+)
/VERT: JP1.2, U1.2' (V)
GND: JP1.5, U1.1 (H-), U1.1' (V-), U1.c (SEL-)
VCC: JP1.1, U1.3 (H+), U1.3' (V+)

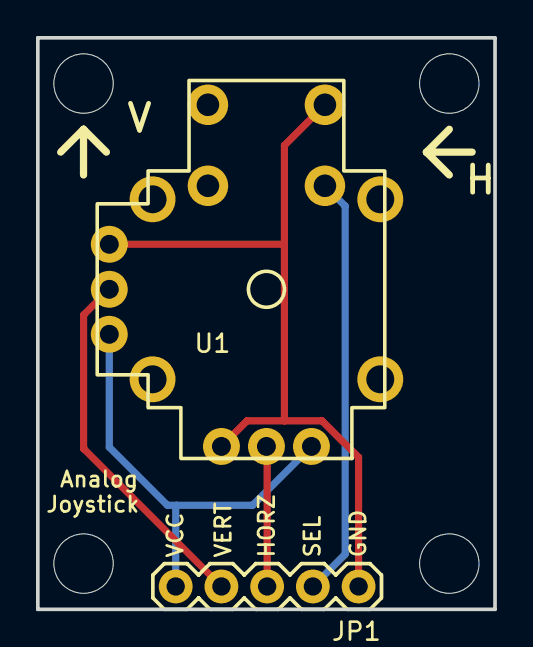
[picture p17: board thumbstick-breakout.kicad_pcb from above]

Board: 2 copper layers, 25.4 x 31.8 mm, 6 parts (0 on the bottom side), 5 nets.

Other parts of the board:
U$3, U$4, U$5, U$6: Screw Hole

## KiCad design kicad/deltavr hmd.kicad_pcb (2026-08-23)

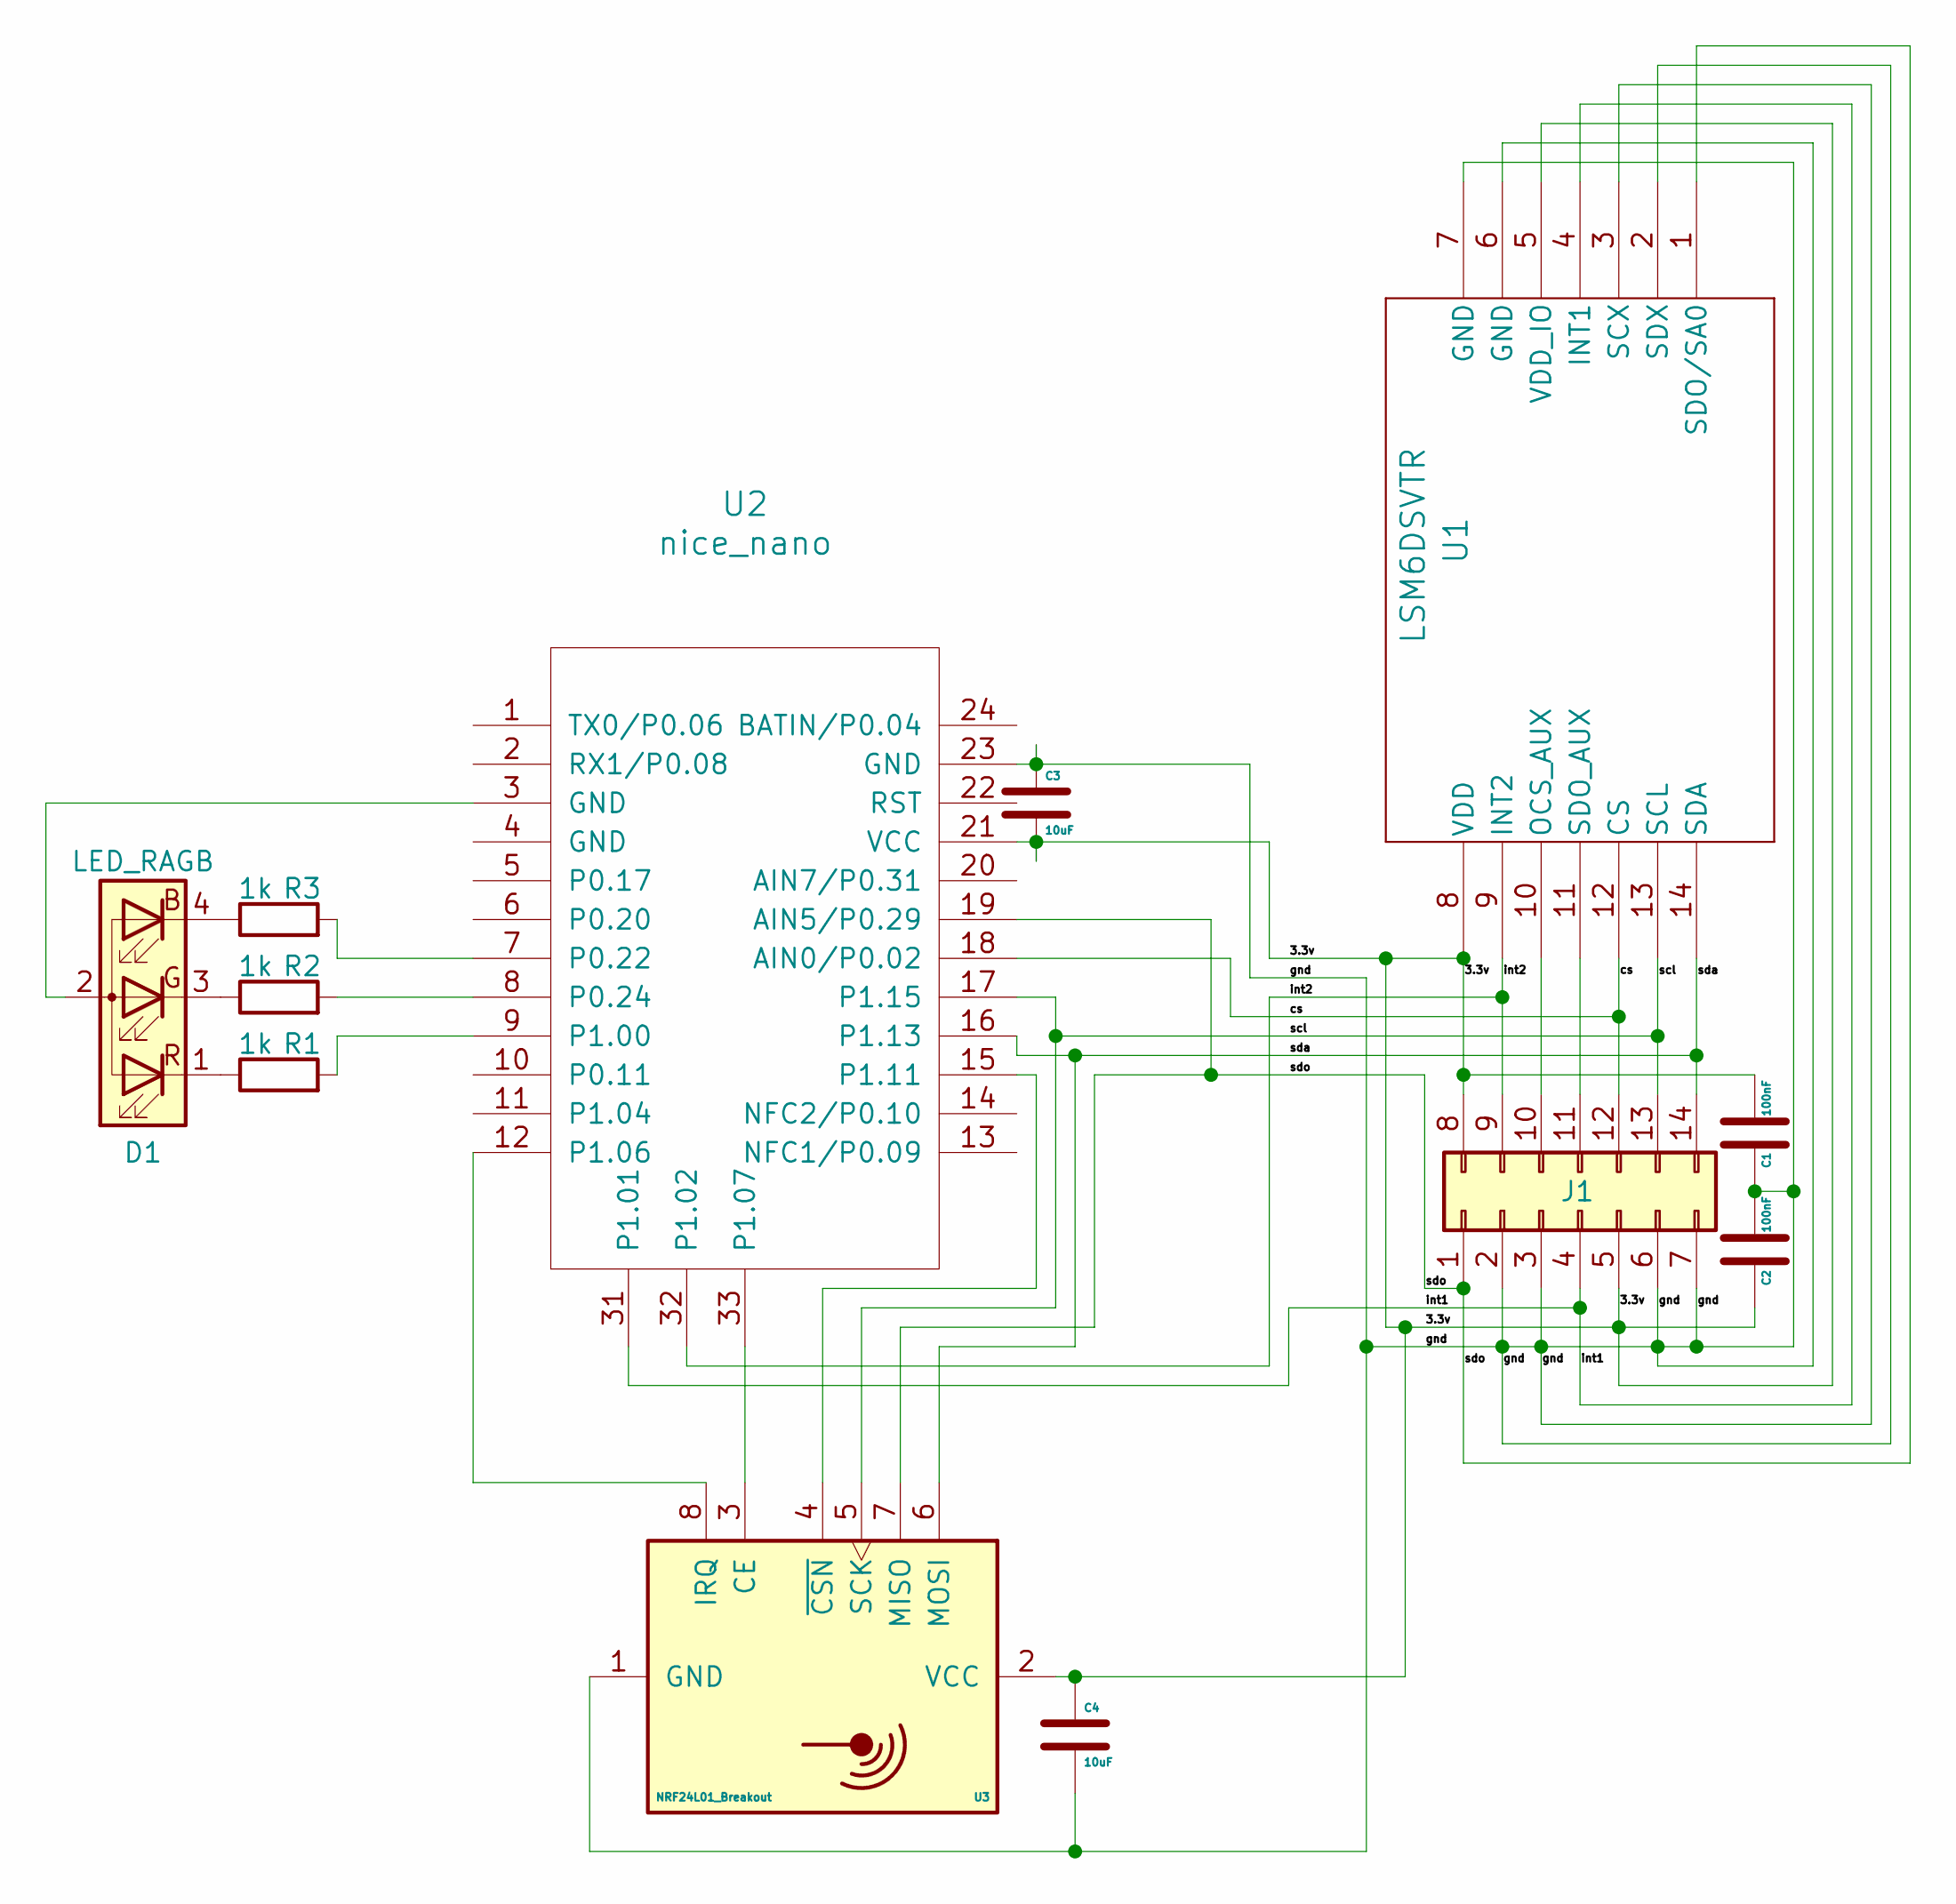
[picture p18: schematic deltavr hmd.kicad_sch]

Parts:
C1, C2: 100nF; C_0603_1608Metric_Pad1.08x0.95mm_HandSolder
C3, C4: 10uF; C_0603_1608Metric_Pad1.08x0.95mm_HandSolder
D1: LED_RAGB; LED_D5.0mm-4_RGB_Wide_Pins
J1: Conn_02x07_Top_Bottom; PinHeader_2x07_P2.54mm_Vertical
R1, R2, R3: 1k; R_0603_1608Metric_Pad0.98x0.95mm_HandSolder
U1: LSM6DSVTR; LGA14-L_2P59X3P1X0P5_STM-M
U2: nice_nano
U3: NRF24L01_Breakout; nRF24L01_Breakout

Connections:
/3.3v: C1.2, C2.1, C3.1, C4.2, J1.5, J1.8, U1.5 (VDD_IO), U1.8 (VDD), U2.21 (VCC), U3.2 (VCC); also elsewhere on the board
/cs: J1.12, U1.12 (CS), U2.18 (AIN0/P0.02)
/int1: J1.4, U1.4 (INT1), U2.31 (P1.01)
/int2: J1.9, U1.9 (INT2), U2.32 (P1.02)
/scl: J1.13, U1.13 (SCL), U2.17 (P1.15), U3.5 (SCK)
/sda: J1.14, U1.14 (SDA), U2.16 (P1.13), U3.6 (MOSI)
/sdo: J1.1, U1.1 (SDO/SA0), U2.19 (AIN5/P0.29), U3.7 (MISO)
unnamed: D1.4 (BK), R3.1
unnamed: D1.3 (GK), R2.1
unnamed: D1.1 (RK), R1.1
unnamed: J1.10, U1.10 (OCS_AUX)
unnamed: J1.11, U1.11 (SDO_AUX)
unnamed: R3.2, U2.7 (P0.22)
unnamed: R2.2, U2.8 (P0.24)
unnamed: R1.2, U2.9 (P1.00)
unnamed: U2.12 (P1.06), U3.8 (IRQ)
unnamed: U2.33 (P1.07), U3.3 (CE)
unnamed: U2.15 (P1.11), U3.4 (~CSN)

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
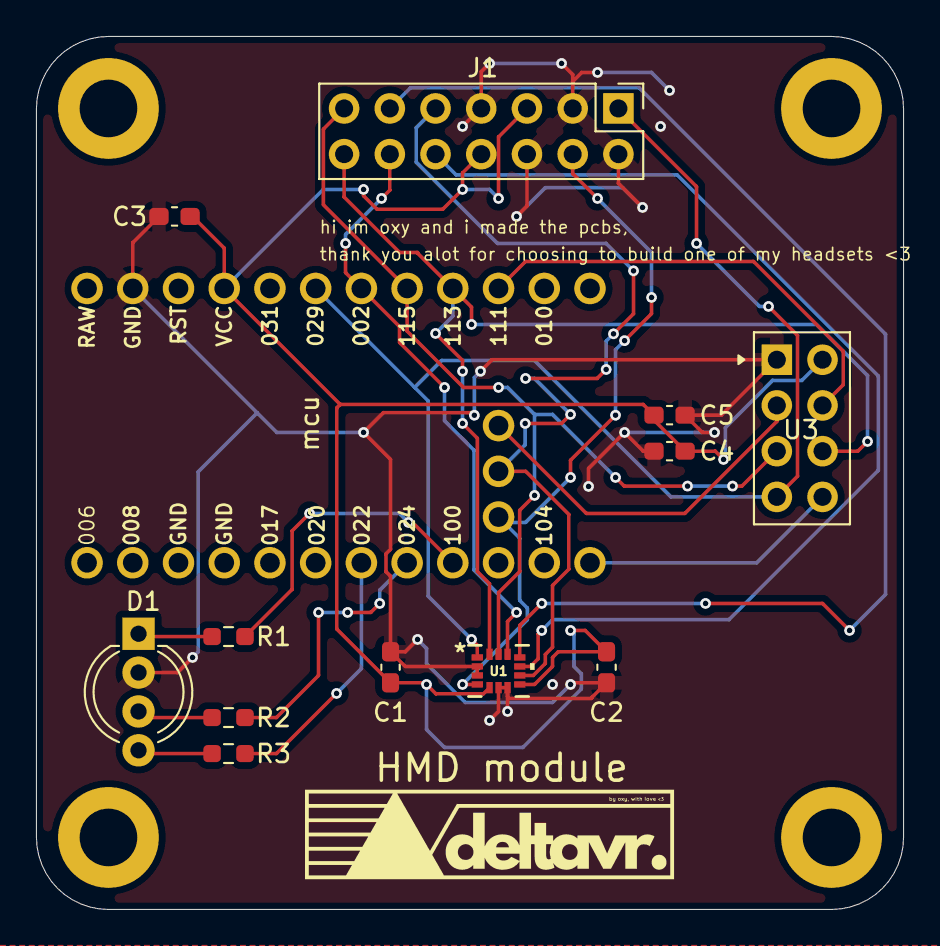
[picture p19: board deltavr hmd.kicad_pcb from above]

Board: 2 copper layers, 48.2 x 48.5 mm, 17 parts (0 on the bottom side), 19 nets.

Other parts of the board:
C5: 100nF; C_0603_1608Metric_Pad1.08x0.95mm_HandSolder
M3 screw, M3 screw#2, M3 screw#3, M3 screw#4: MountingHole_3.2mm_M3_DIN965_Pad

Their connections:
/3.3v: C5.2; also elsewhere on the board

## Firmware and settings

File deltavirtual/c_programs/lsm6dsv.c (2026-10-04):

// Minimal raw-SPI LSM6DSV driver (polling, no FIFO, no interrupts).
// Uses the same spi_transfer / gpio / delay helpers as nrf24_raw.c.
#include <stdint.h>
#include <stdbool.h>
#include <string.h>

// ---- YOU PROVIDE THESE (same as for the radio driver) ----
// spi_transfer: full duplex, mode 0, MSB first.
void spi_transfer(const uint8_t *tx, uint8_t *rx, uint32_t len);
void gpio_write(uint32_t pin, bool level);
void delay_us(uint32_t us);
void delay_ms(uint32_t ms);

// nRF52 pin number = port * 32 + pin
#define PIN(port, n) ((port) * 32 + (n))
#define IMU_CS   PIN(0, 2)    // Pro Micro 18 -> LSM6DSV pin 12
#define IMU_INT1 PIN(1, 1)    // not used by this driver
#define IMU_INT2 PIN(1, 2)    // not used by this driver

// Registers
#define IMU_CTRL1      0x10   // accel ODR + mode
#define IMU_CTRL2      0x11   // gyro ODR + mode
#define IMU_CTRL3      0x12   // BDU, IF_INC, SW_RESET
#define IMU_CTRL6      0x15   // gyro full scale
#define IMU_CTRL8      0x17   // accel full scale
#define IMU_WHO_AM_I   0x0F
#define IMU_STATUS     0x1E
#define IMU_OUT_TEMP_L 0x20
#define IMU_OUTX_L_G   0x22   // 6 bytes gyro, then 6 bytes accel at 0x28

#define IMU_ID 0x70

typedef struct {
    int32_t accel_mg[3];      // milli-g
    int32_t gyro_mdps[3];     // milli-degrees per second
    int32_t temp_mc;          // milli-degrees C
} imu_sample_t;

// One SPI transfer per access, CS low for the whole thing.
// Bit 7 of the first byte: 1 = read, 0 = write. Address auto-increments.
static void imu_read(uint8_t reg, uint8_t *out, uint8_t len)
{
    uint8_t txb[1 + 12] = { 0 }, rxb[1 + 12];
    txb[0] = 0x80 | reg;
    gpio_write(IMU_CS, 0);
    spi_transfer(txb, rxb, len + 1);
    gpio_write(IMU_CS, 1);
    memcpy(out, &rxb[1], len);
}

static uint8_t imu_read_reg(uint8_t reg)
{
    uint8_t v;
    imu_read(reg, &v, 1);
    return v;
}

static void imu_write_reg(uint8_t reg, uint8_t value)
{
    uint8_t txb[2] = { reg & 0x7F, value };
    gpio_write(IMU_CS, 0);
    spi_transfer(txb, NULL, 2);
    gpio_write(IMU_CS, 1);
}

// Returns true if the chip answered with the expected WHO_AM_I.
bool imu_init(void)
{
    gpio_write(IMU_CS, 1);
    delay_ms(20);                               // power-on settling

    if (imu_read_reg(IMU_WHO_AM_I) != IMU_ID) {
        return false;
    }

    imu_write_reg(IMU_CTRL3, 0x01);             // SW_RESET
    for (int i = 0; i < 100 && (imu_read_reg(IMU_CTRL3) & 0x01); i++) {
        delay_ms(1);
    }

    imu_write_reg(IMU_CTRL3, 0x44);             // BDU = 1, IF_INC = 1
    imu_write_reg(IMU_CTRL8, 0x01);             // accel +-4 g   (0.122 mg/LSB)
    imu_write_reg(IMU_CTRL6, 0x04);             // gyro  +-2000 dps (70 mdps/LSB)
    imu_write_reg(IMU_CTRL1, 0x06);             // accel 120 Hz, high-performance
    imu_write_reg(IMU_CTRL2, 0x06);             // gyro  120 Hz, high-performance
    delay_ms(20);                               // let the first samples settle
    return true;
}

static int16_t le16(const uint8_t *p)
{
    return (int16_t)((uint16_t)p[0] | ((uint16_t)p[1] << 8));
}

// Returns true if a fresh sample was read (accel and gyro data-ready set).
bool imu_read_sample(imu_sample_t *s)
{
    if ((imu_read_reg(IMU_STATUS) & 0x03) != 0x03) {
        return false;
    }

    uint8_t d[12];
    imu_read(IMU_OUTX_L_G, d, 12);              // gyro X,Y,Z then accel X,Y,Z
    for (int i = 0; i < 3; i++) {
        s->gyro_mdps[i] = (int32_t)le16(&d[2 * i]) * 70;
        s->accel_mg[i]  = (int32_t)le16(&d[6 + 2 * i]) * 122 / 1000;
    }

    uint8_t t[2];
    imu_read(IMU_OUT_TEMP_L, t, 2);
    s->temp_mc = 25000 + ((int32_t)le16(t) * 1000) / 256;   // 256 LSB/degC, 0 at 25 C
    return true;
}

/* Usage:
 *
 * if (!imu_init()) { // print "IMU not found" on the UART }
 * imu_sample_t s;
 * while (1) {
 *     if (imu_read_sample(&s)) {
 *         // print s.accel_mg[0..2], s.gyro_mdps[0..2], s.temp_mc on the UART
 *     }
 *     delay_ms(10);
 * }
 */

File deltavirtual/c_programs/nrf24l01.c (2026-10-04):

// Minimal raw-SPI NRF24L01 driver. Same code for both boards;
// one calls nrf_start_tx(), the other nrf_start_rx().
#include <stdint.h>
#include <stdbool.h>
#include <string.h>

// ---- YOU PROVIDE THESE (SPIM2 transfer, GPIO, delays) ----
// spi_transfer: full duplex, mode 0, MSB first, rx may be NULL.
void spi_transfer(const uint8_t *tx, uint8_t *rx, uint32_t len);
void gpio_write(uint32_t pin, bool level);
bool gpio_read(uint32_t pin);
void delay_us(uint32_t us);
void delay_ms(uint32_t ms);

// nRF52 pin number = port * 32 + pin
#define PIN(port, n) ((port) * 32 + (n))
#define NRF_CE   PIN(1, 7)    // Pro Micro 33 -> module pin 3
#define NRF_CSN  PIN(1, 11)   // Pro Micro 15 -> module pin 4
#define NRF_IRQ  PIN(1, 6)    // Pro Micro 12 -> module pin 8 (optional, active low)

// Commands
#define CMD_R_REG    0x00
#define CMD_W_REG    0x20
#define CMD_R_RX     0x61
#define CMD_W_TX     0xA0
#define CMD_FLUSH_TX 0xE1
#define CMD_FLUSH_RX 0xE2
#define CMD_NOP      0xFF

// Registers
#define REG_CONFIG      0x00
#define REG_EN_AA       0x01
#define REG_EN_RXADDR   0x02
#define REG_SETUP_AW    0x03
#define REG_SETUP_RETR  0x04
#define REG_RF_CH       0x05
#define REG_RF_SETUP    0x06
#define REG_STATUS      0x07
#define REG_RX_ADDR_P0  0x0A
#define REG_TX_ADDR     0x10
#define REG_RX_PW_P0    0x11
#define REG_FIFO_STATUS 0x17

// STATUS bits
#define ST_RX_DR  0x40
#define ST_TX_DS  0x20
#define ST_MAX_RT 0x10

#define PAYLOAD_LEN 32
#define RF_CHANNEL  76
static const uint8_t ADDR[5] = { 'D', 'V', 'R', '0', '1' };   // same on both boards

// One SPI transfer per command, with CSN low for the whole thing.
// (The Renode model ends a command when CSN goes high.)
static uint8_t nrf_cmd(uint8_t cmd, const uint8_t *tx, uint8_t *rx, uint8_t len)
{
    uint8_t txb[1 + PAYLOAD_LEN], rxb[1 + PAYLOAD_LEN];
    txb[0] = cmd;
    if (tx) memcpy(&txb[1], tx, len); else memset(&txb[1], 0, len);

    gpio_write(NRF_CSN, 0);
    spi_transfer(txb, rxb, len + 1);
    gpio_write(NRF_CSN, 1);

    if (rx) memcpy(rx, &rxb[1], len);
    return rxb[0];                      // first byte back is always STATUS
}

static void    write_reg(uint8_t reg, uint8_t v) { nrf_cmd(CMD_W_REG | reg, &v, NULL, 1); }
static uint8_t read_reg(uint8_t reg)             { uint8_t v; nrf_cmd(CMD_R_REG | reg, NULL, &v, 1); return v; }
static void    write_addr(uint8_t reg)           { nrf_cmd(CMD_W_REG | reg, ADDR, NULL, 5); }

static void nrf_common_init(void)
{
    gpio_write(NRF_CSN, 1);
    gpio_write(NRF_CE, 0);
    delay_ms(5);

    write_reg(REG_SETUP_AW, 0x03);          // 5-byte addresses
    write_reg(REG_RF_CH, RF_CHANNEL);
    write_reg(REG_RF_SETUP, 0x06);          // 1 Mbps, 0 dBm
    write_reg(REG_EN_AA, 0x01);             // auto-ack on pipe 0
    write_reg(REG_SETUP_RETR, 0x00);
    write_reg(REG_RX_PW_P0, PAYLOAD_LEN);   // fixed payload length
    nrf_cmd(CMD_FLUSH_TX, NULL, NULL, 0);
    nrf_cmd(CMD_FLUSH_RX, NULL, NULL, 0);
    write_reg(REG_STATUS, ST_RX_DR | ST_TX_DS | ST_MAX_RT);   // clear flags
}

// ---- Receiver ----
void nrf_start_rx(void)
{
    nrf_common_init();
    write_addr(REG_RX_ADDR_P0);
    write_reg(REG_EN_RXADDR, 0x01);         // pipe 0 only
    write_reg(REG_CONFIG, 0x0B);            // EN_CRC | PWR_UP | PRIM_RX
    delay_ms(2);                            // power-up settling
    gpio_write(NRF_CE, 1);                  // CE high = listening
}

// Returns true and fills buf (PAYLOAD_LEN bytes) if a packet was waiting.
bool nrf_receive(uint8_t *buf)
{
    if (read_reg(REG_FIFO_STATUS) & 0x01) return false;   // RX_EMPTY
    nrf_cmd(CMD_R_RX, NULL, buf, PAYLOAD_LEN);
    if (read_reg(REG_FIFO_STATUS) & 0x01)
        write_reg(REG_STATUS, ST_RX_DR);                   // FIFO drained: clear flag
    return true;
}

// ---- Transmitter ----
void nrf_start_tx(void)
{
    nrf_common_init();
    write_addr(REG_TX_ADDR);
    write_addr(REG_RX_ADDR_P0);             // pipe 0 receives the auto-ack
    write_reg(REG_EN_RXADDR, 0x01);
    write_reg(REG_CONFIG, 0x0A);            // EN_CRC | PWR_UP, PRIM_RX = 0
    delay_ms(2);
}

// data must be PAYLOAD_LEN bytes. Returns true if the packet was delivered.
bool nrf_send(const uint8_t *data)
{
    nrf_cmd(CMD_W_TX, data, NULL, PAYLOAD_LEN);
    gpio_write(NRF_CE, 1);
    delay_us(15);                           // CE pulse > 10 us
    gpio_write(NRF_CE, 0);

    uint8_t st = 0;
    for (int i = 0; i < 1000; i++) {        // poll STATUS via NOP
        st = nrf_cmd(CMD_NOP, NULL, NULL, 0);
        if (st & (ST_TX_DS | ST_MAX_RT)) break;
        delay_us(100);
    }
    write_reg(REG_STATUS, ST_TX_DS | ST_MAX_RT);
    if (st & ST_MAX_RT) nrf_cmd(CMD_FLUSH_TX, NULL, NULL, 0);
    return (st & ST_TX_DS) != 0;
}

/* Usage:
 *
 * // controller
 * nrf_start_tx();
 * delay_ms(100);                       // let the receiver start listening first
 * uint8_t msg[PAYLOAD_LEN] = "hello";
 * bool ok = nrf_send(msg);             // print ok on UART
 *
 * // headset
 * nrf_start_rx();
 * uint8_t buf[PAYLOAD_LEN];
 * while (1) { if (nrf_receive(buf)) { /\* print buf on UART *\/ } }
 */

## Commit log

2026-07-02 stuff from hades imported by ag
    [Component list.xlsx]
2026-08-17 massive work, logo, hmd pcb fully done etc
    [LGA14-L_2p59x3P1x0P5_STM.step, deltavr hmd.kicad_pcb, deltavr hmd.kicad_sch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]
2026-08-17 kicad files after save for final pcb for hmd module
    [deltavr hmd.kicad_pcb, deltavr hmd.kicad_sch]
2026-08-19 con troller (r) is dojne
    [DGS0010A.stp, deltavr_controller.kicad_pcb, deltavr_controller.kicad_sch]
2026-08-22 controllers are FUVCKING DONNE AYYYAYYYY
    [deltavr_controller.kicad_pcb, deltavr_controller.kicad_sch]
2026-08-23 hmd and controller done officially
    [deltavr hmd.kicad_pcb, deltavr hmd.kicad_sch]
2026-08-24 small chnages
    [deltavr hmd.kicad_sch]
2026-09-07 cleaning for repo
    clean repo
    [Component list.xlsx, deltavr.stl]
2026-09-07 Vendor nordic-lib-kicad + thumbstick-breakout (fixes untracked libs), fix sym/fp lib tables, update .gitignore, remove AI helper docs
    [nRF54L15-CAXX_Reference_Design.kicad_sch, nRF54L15-QFXX_Reference_Design.kicad_sch, nRF54LM20A-PAXX_Reference_Design.kicad_sch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]
2026-09-07 Restructure to controller R, add JLCPCB gerbers + v1.0.0 release package (gerbers zips, BOMs, ibom, schematic PDFs, renders, release notes)
    [deltavr hmd-bom.csv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]
2026-09-07 Drop redundant gerber zip duplicates (folders are canonical)
2026-09-20 bunch of stuff to comit
    [deltavr hmd.step, deltavr hmd.stl]
2026-09-22 better files
    i did good job, made better pcb / gpio pin connection descriptions !!!!!!!!
2026-10-18 Create Bill of Materials.md
2026-10-18 Update Bill of Materials.md

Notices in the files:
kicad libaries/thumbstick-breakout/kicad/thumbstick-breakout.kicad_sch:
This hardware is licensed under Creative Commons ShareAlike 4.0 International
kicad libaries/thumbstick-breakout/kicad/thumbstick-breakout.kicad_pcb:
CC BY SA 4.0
